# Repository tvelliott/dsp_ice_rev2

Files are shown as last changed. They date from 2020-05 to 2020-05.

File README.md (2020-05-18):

<html>
<b>480 MHz STM32H743 + ICE40 8K FGPA development board with 10/100 Ethernet interface 
<BR>
<BR><B>DSP_ICE_REV2
<BR>
<p>
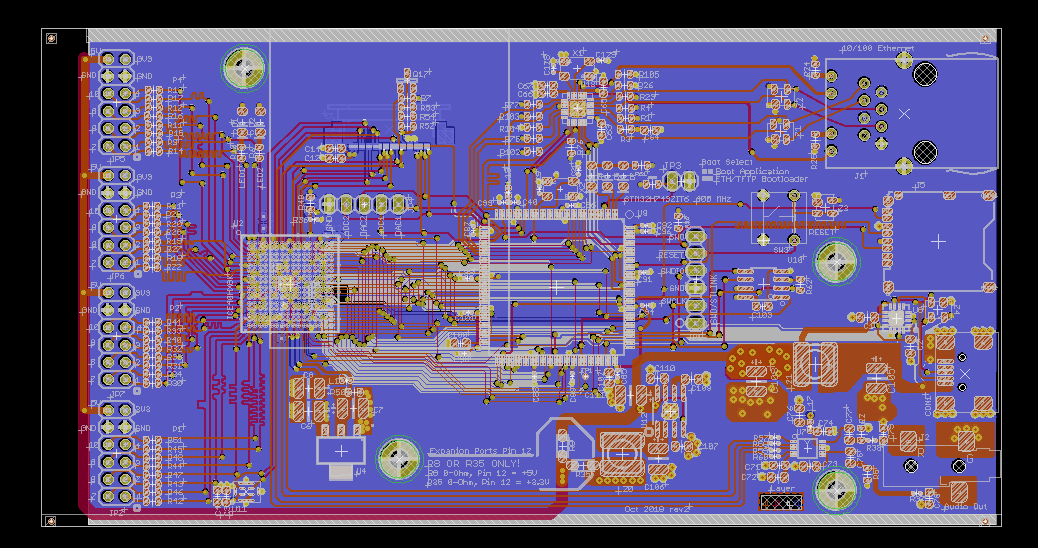
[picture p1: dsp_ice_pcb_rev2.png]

<BR>
<BR>
Features
<BR>
<BR>
<PRE>
16-bit FSMC Interface between MCU <> FPGA  (DMA is supported)
3.5mm audio jack with high quality I2S DAC.  I2S can be generated from FPGA or MCU
FPGA clock input / PLL is fed from MCU MC0 output
Low Noise 3.3V supply
4 PMOD-style ports with 3.3V or 5V selectable voltages
10/100 Mbps Ethernet Interface  (DMA supported,  90+ Mbps IPerf results)
PDM Microphone connected to FPGA
</PRE>
  
<BR><BR>If you are looking for something similar, but with firmware / HDL code already available,  take a look at DSP_ICE Rev 1 here
<BR>https://github.com/tvelliott/dsp_ice 
</html>

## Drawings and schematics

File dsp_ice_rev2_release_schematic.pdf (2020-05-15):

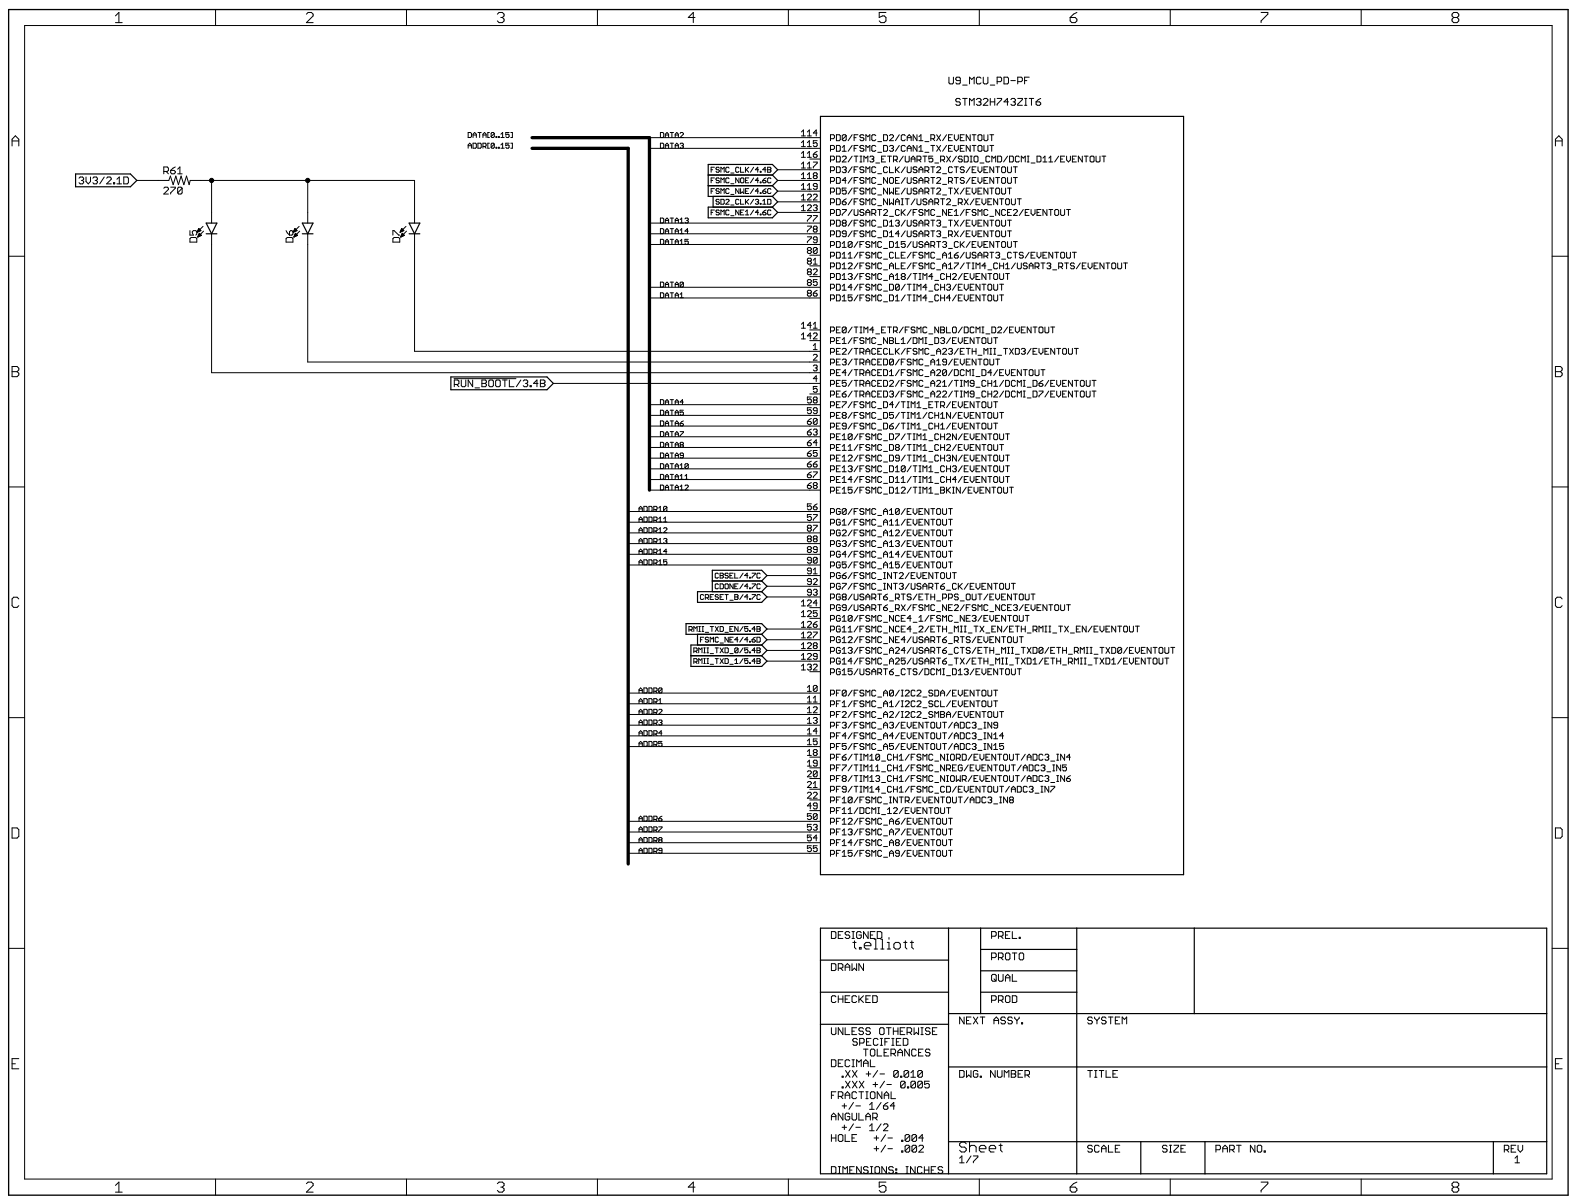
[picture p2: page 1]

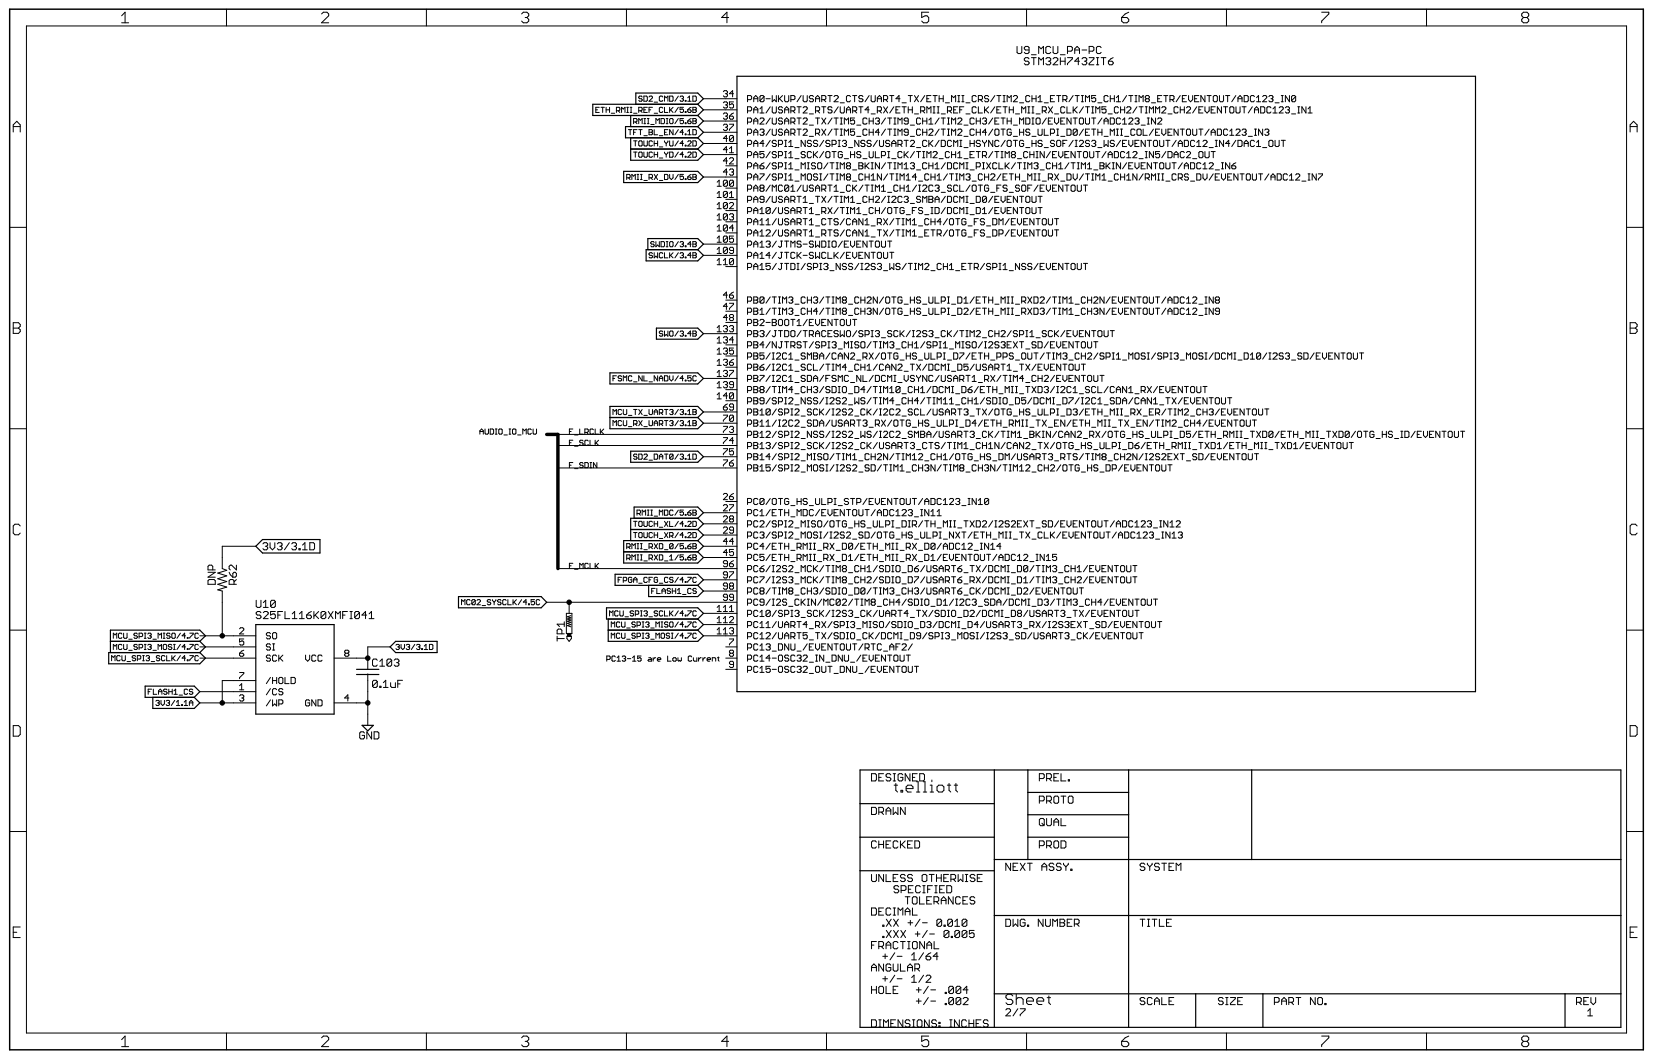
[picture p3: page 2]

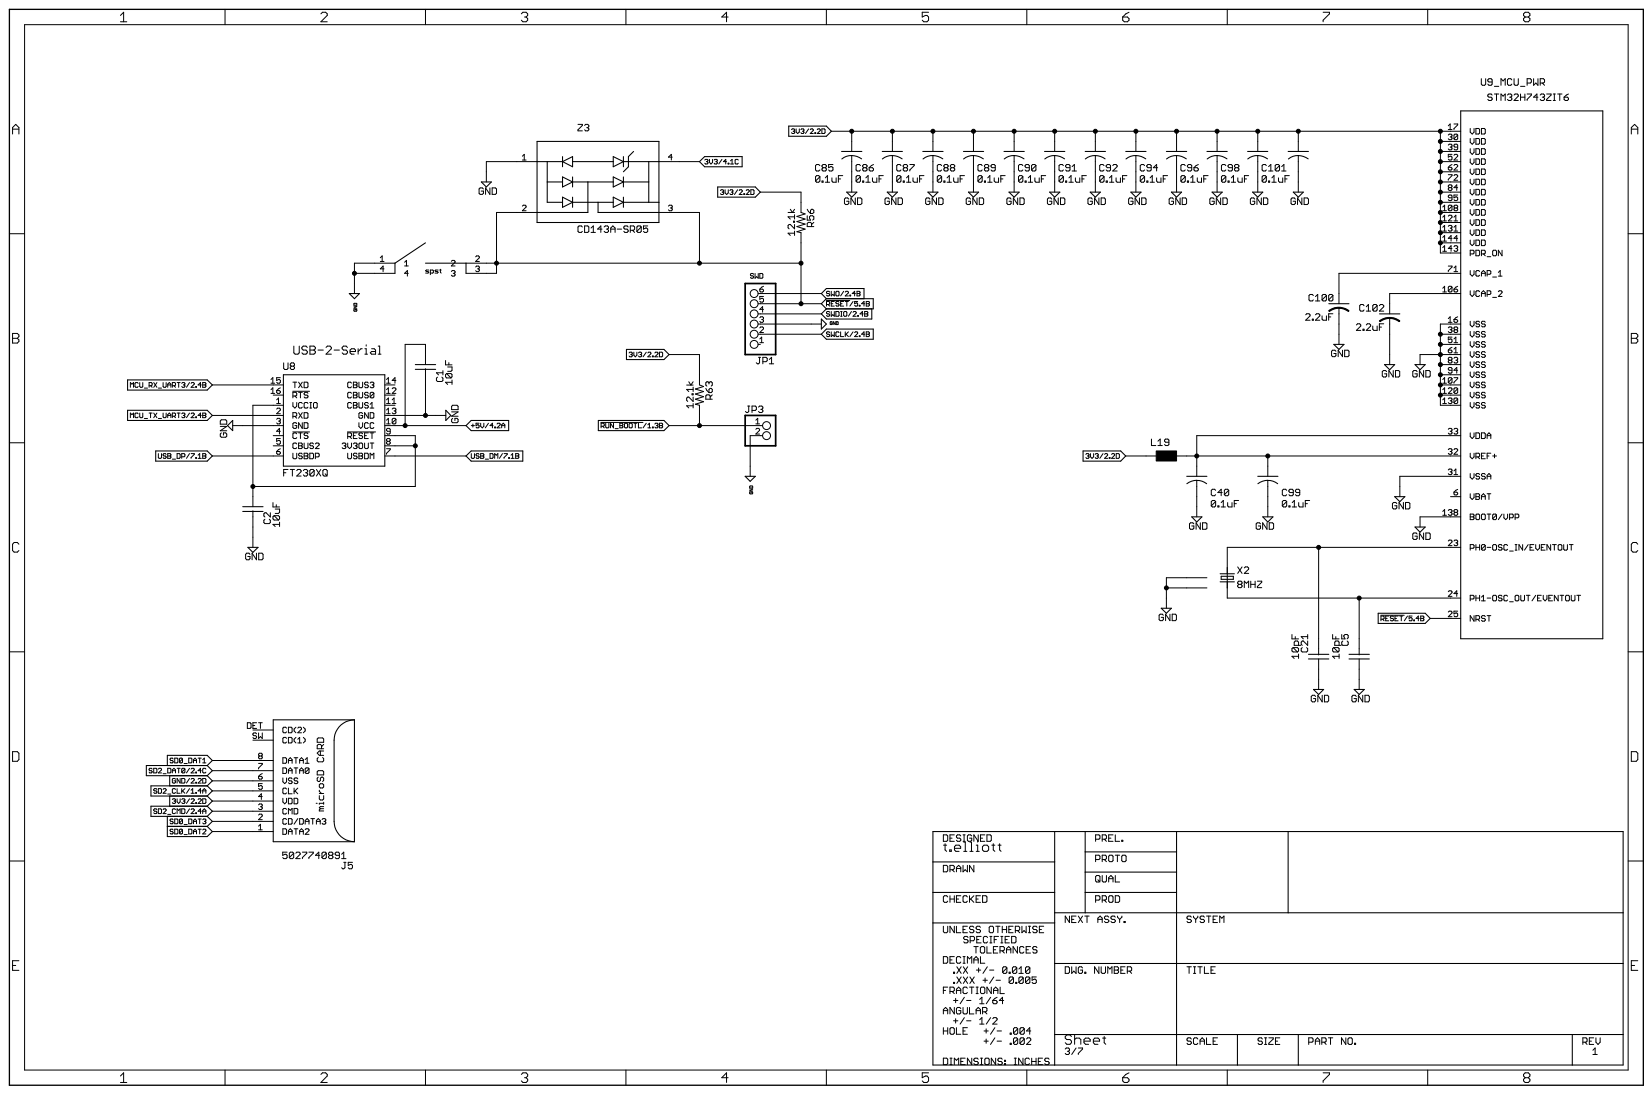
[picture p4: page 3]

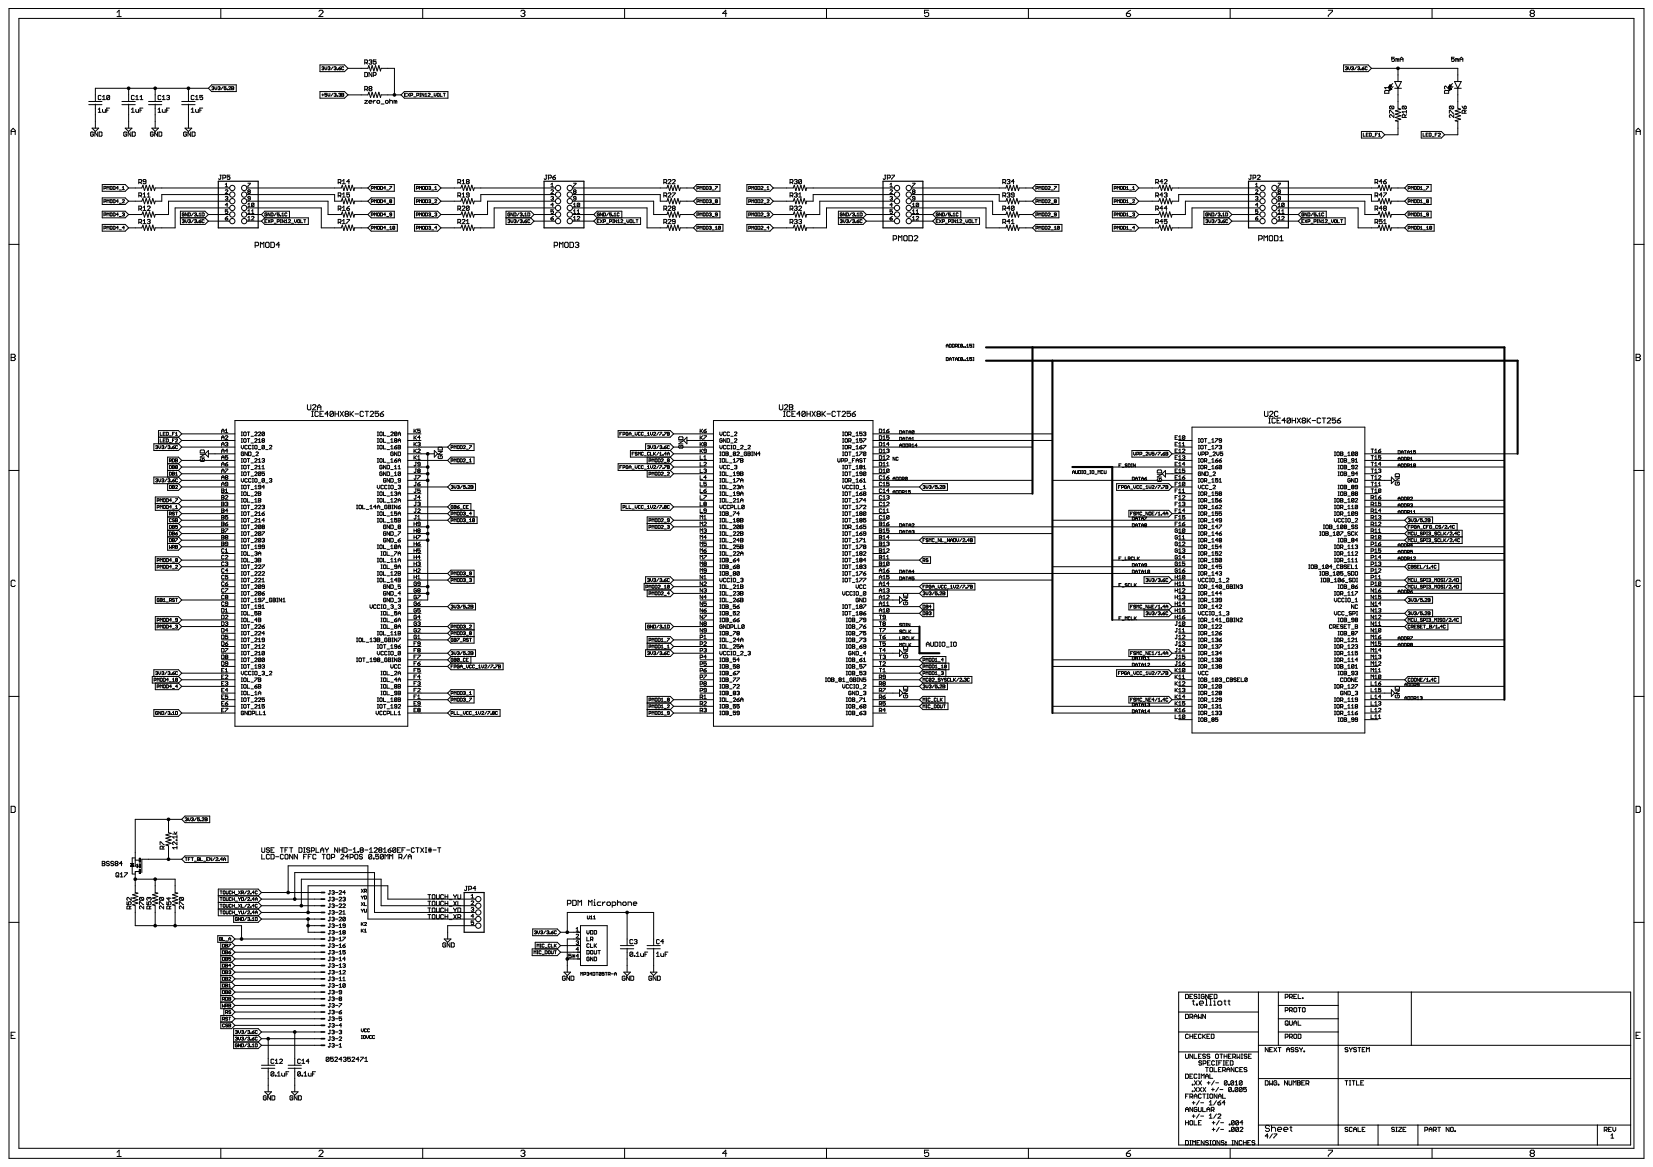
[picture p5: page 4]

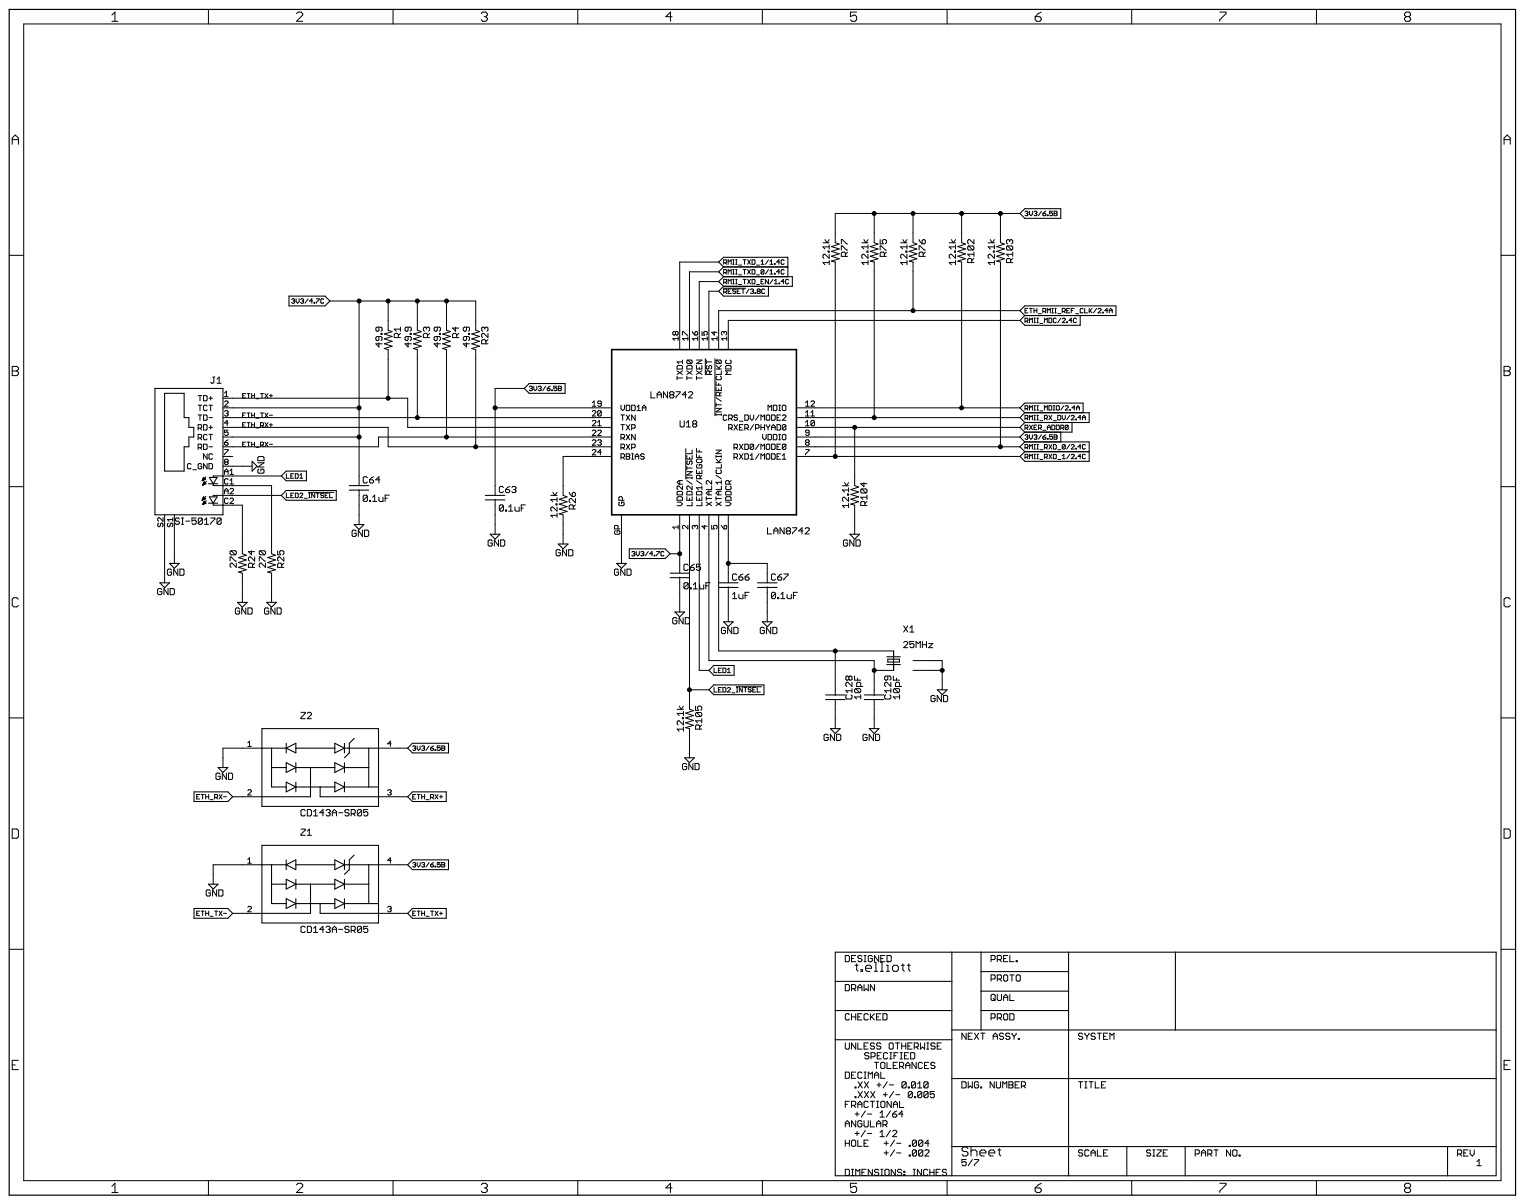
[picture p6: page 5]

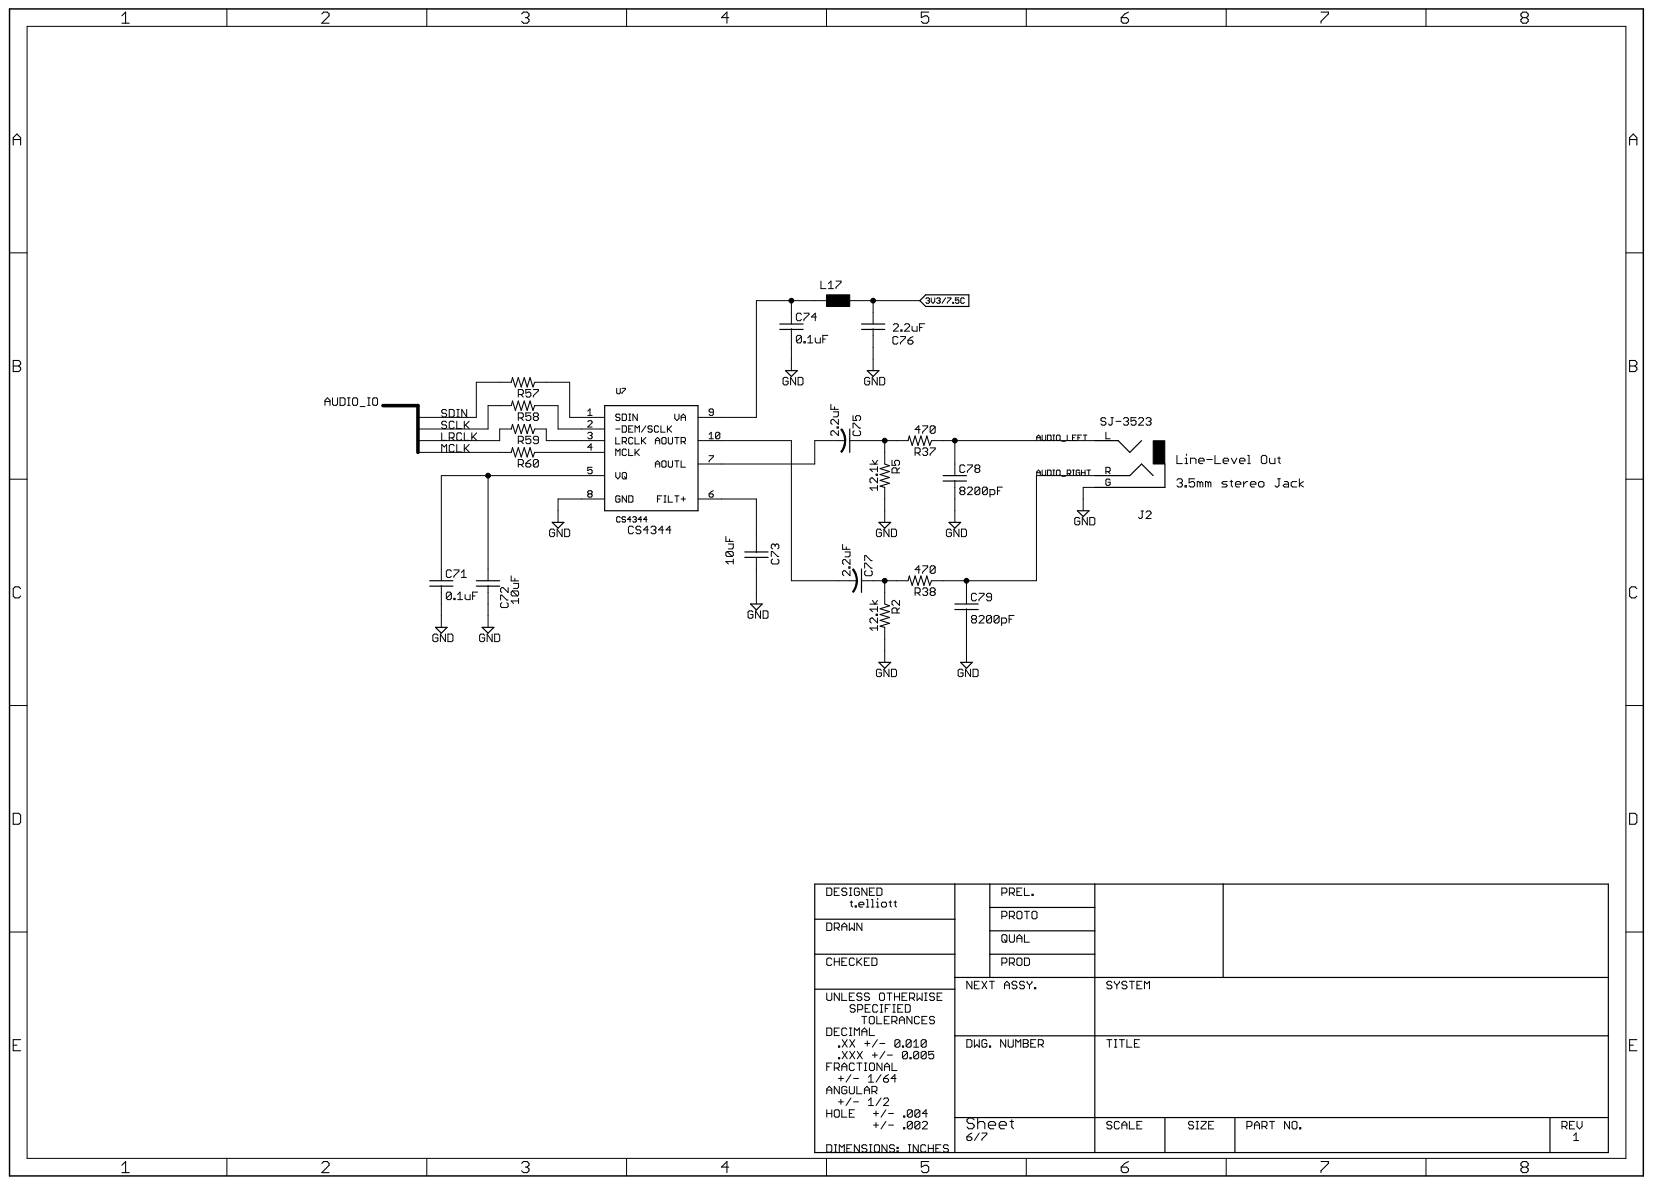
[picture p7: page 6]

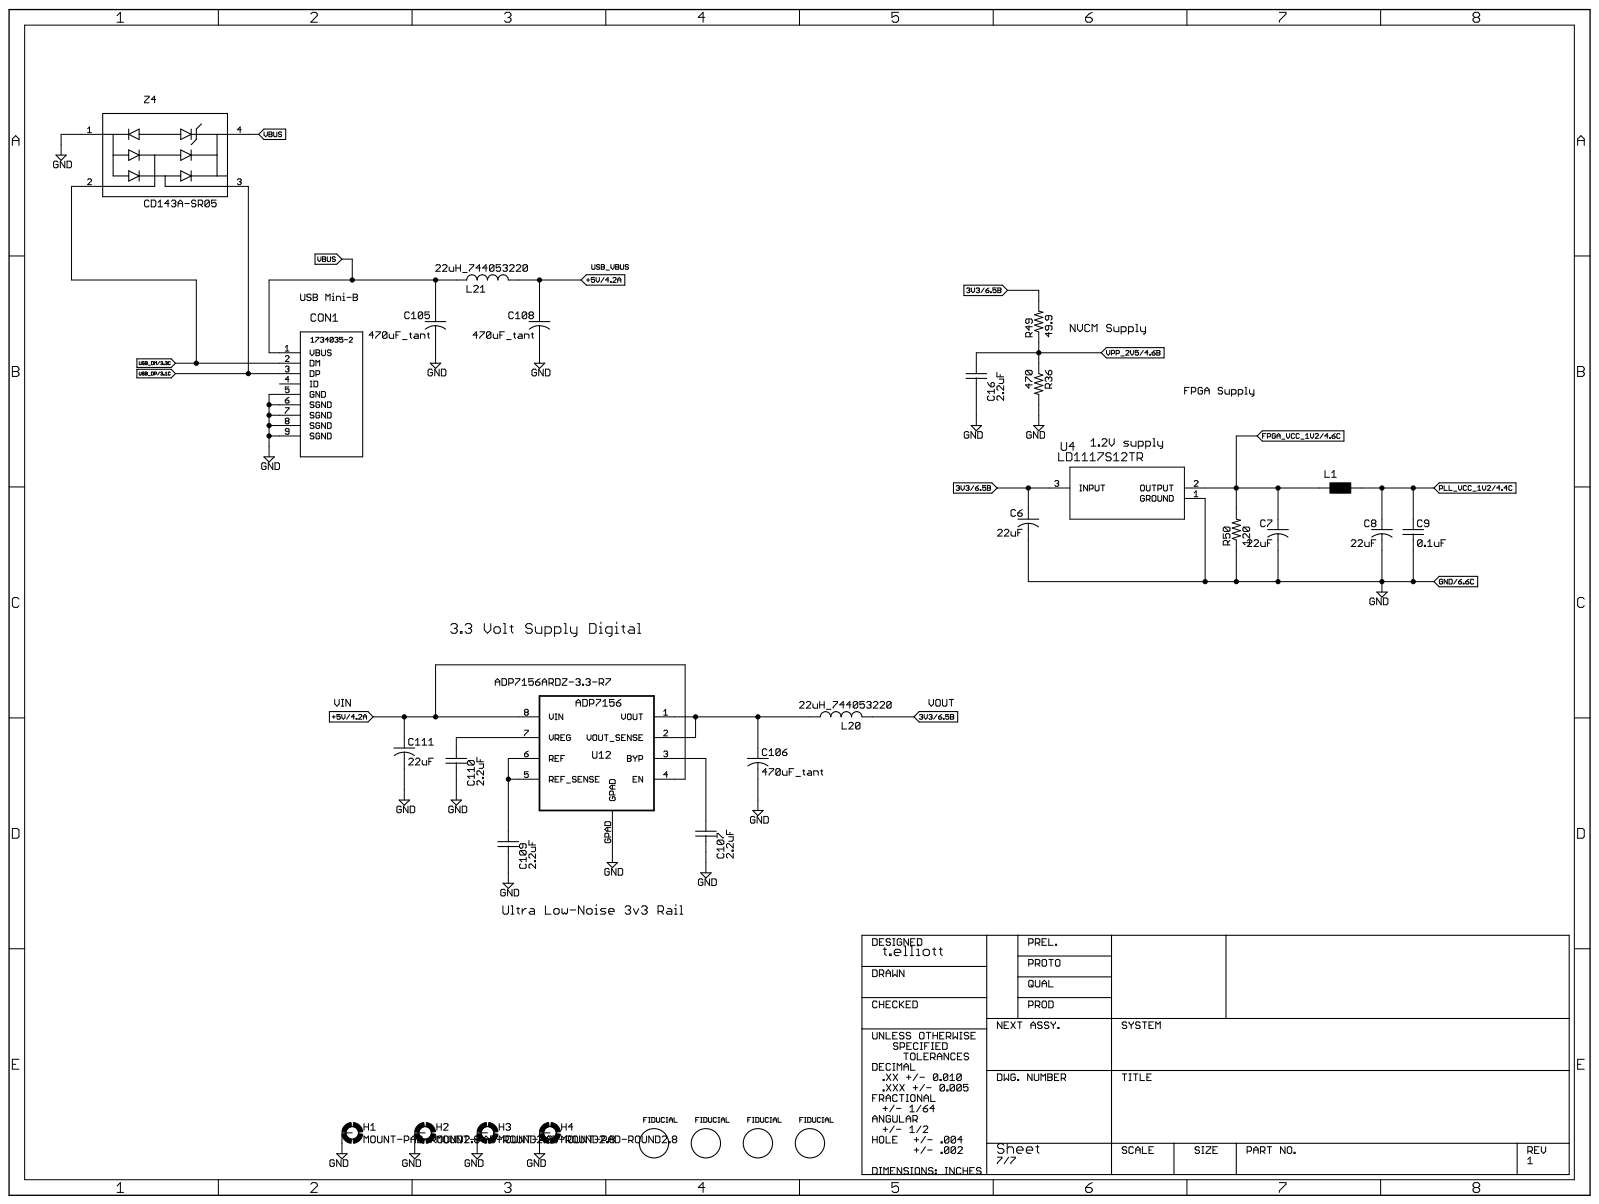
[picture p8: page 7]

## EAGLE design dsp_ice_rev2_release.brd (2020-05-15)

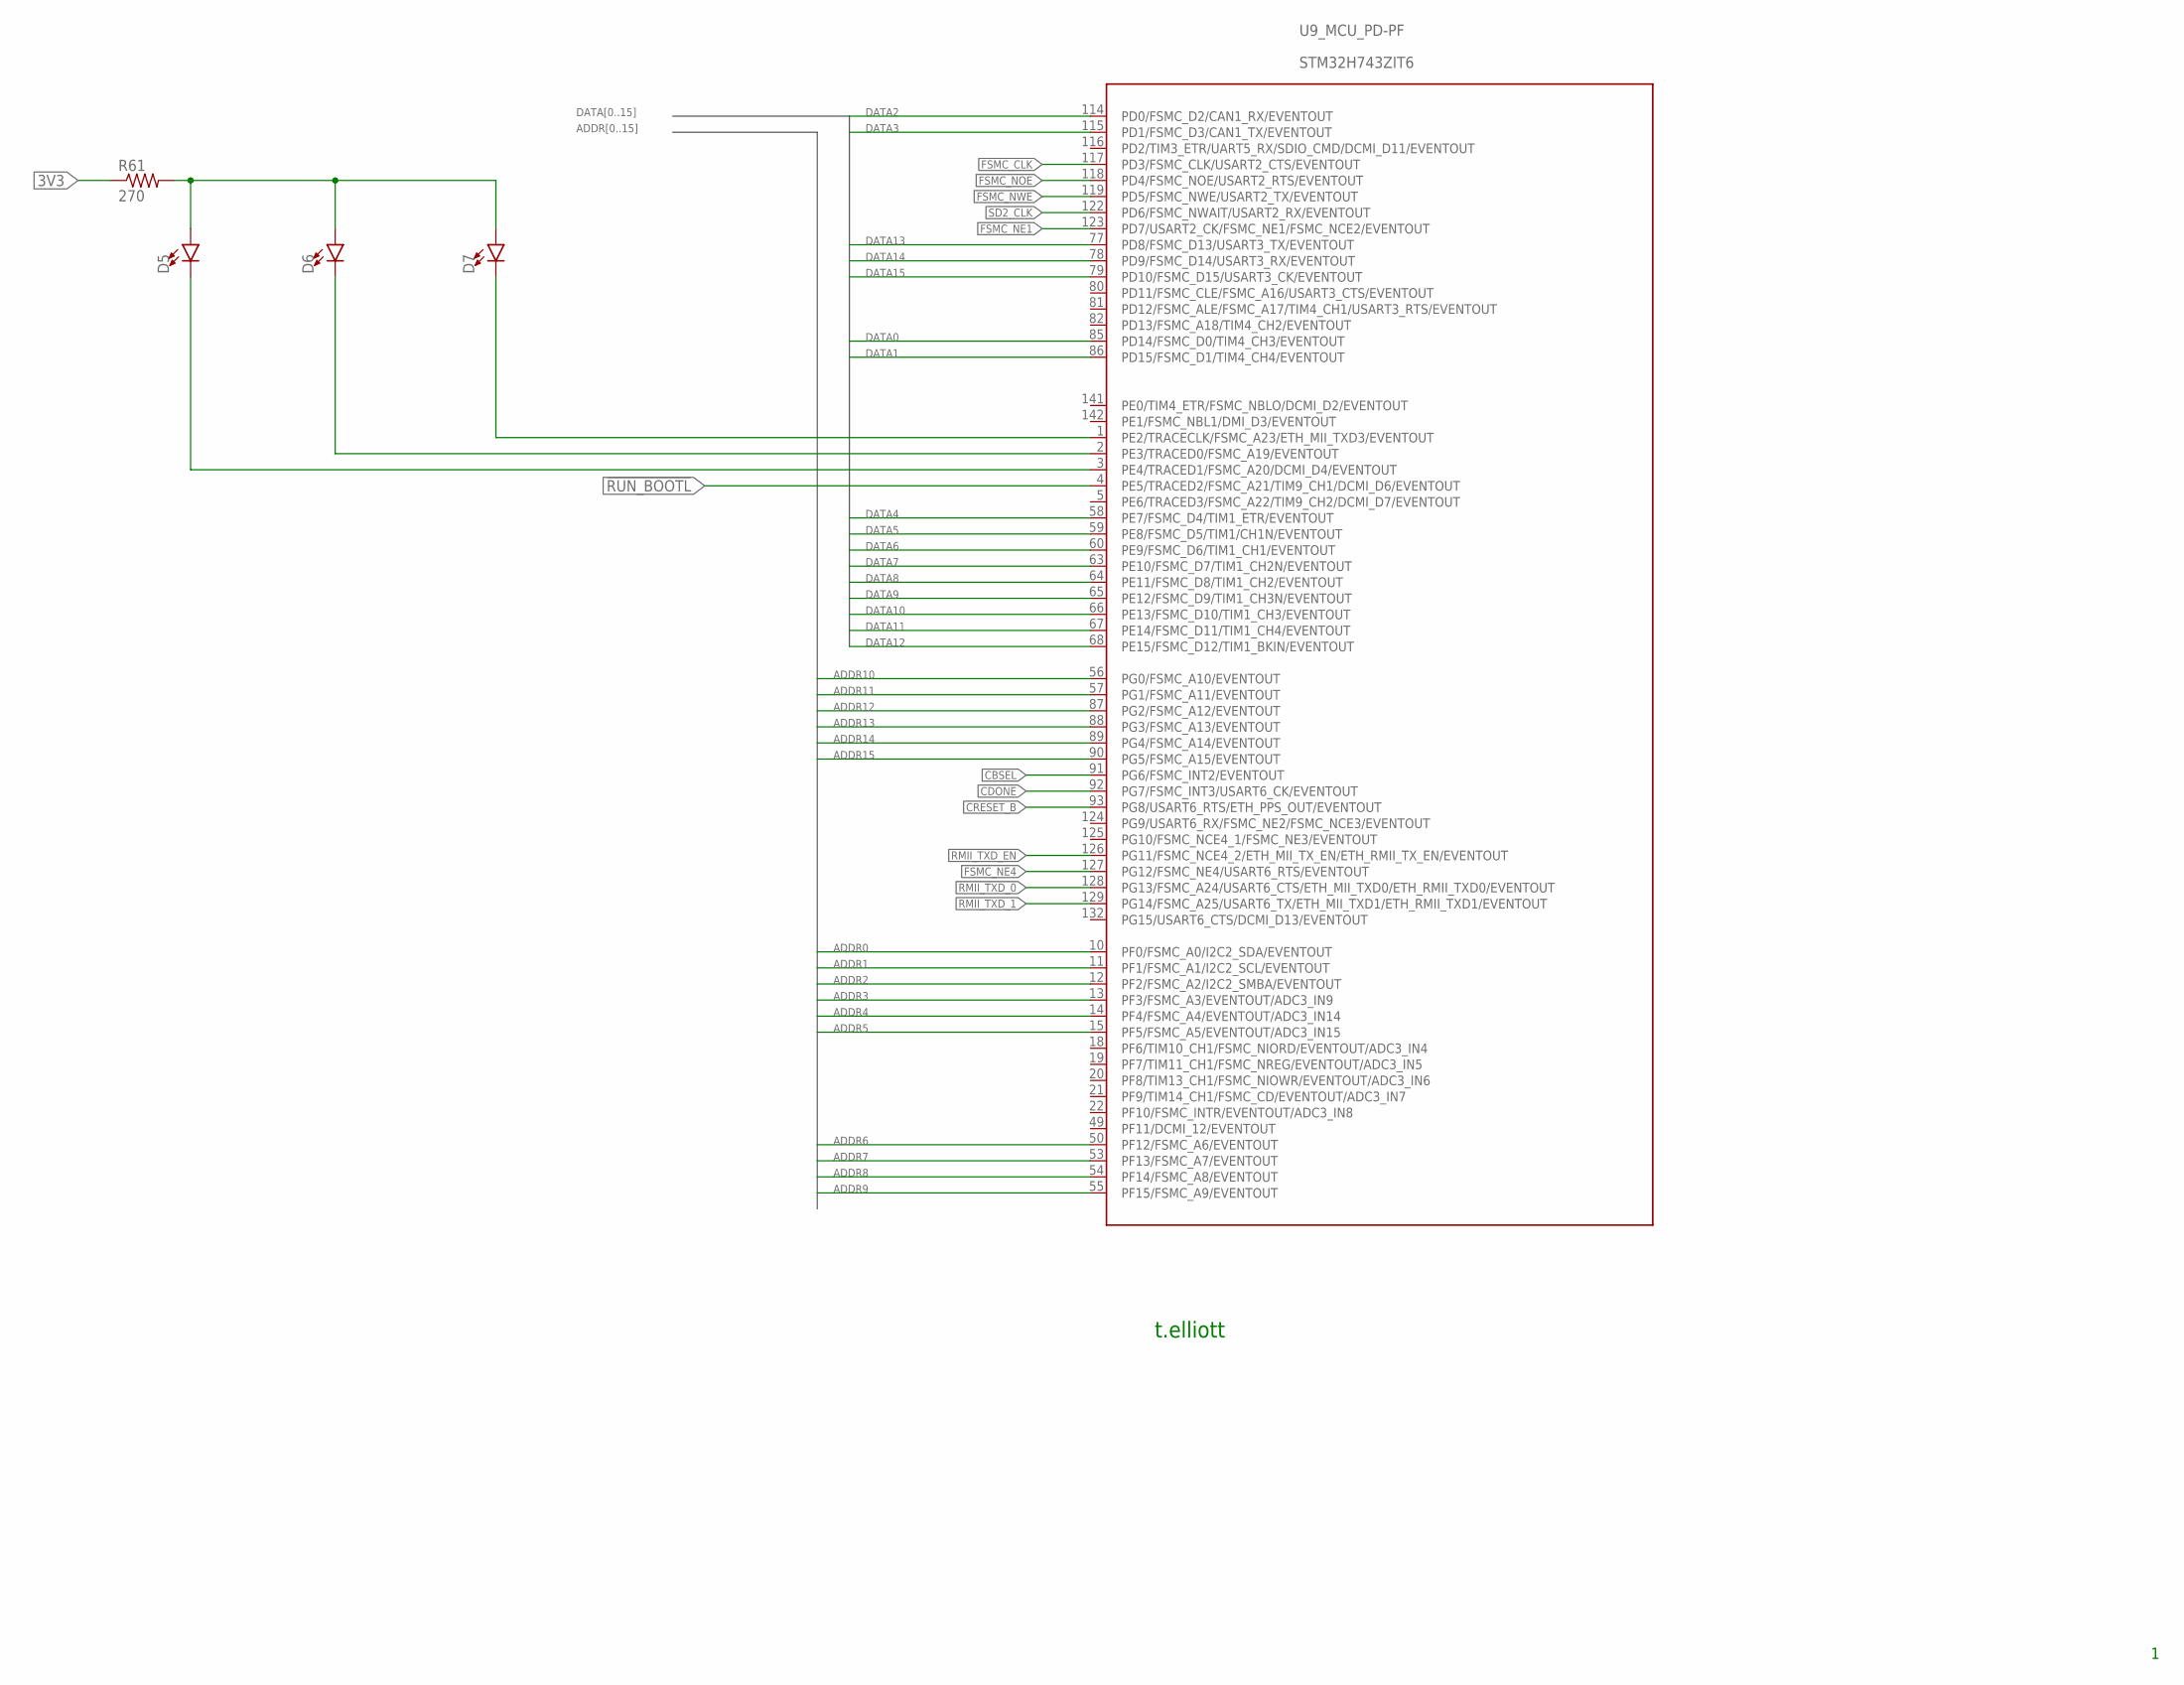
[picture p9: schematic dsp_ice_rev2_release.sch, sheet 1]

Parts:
D5, D6, D7: LED1206; LED-1206
R61: 270; R0603
U9: STM32H743ZIT6; STM32F407_144

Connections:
3V3: R61.1; also elsewhere on the board
!RUN_BOOTL: U9.4 (PE5/TRACED2/FSMC_A21/TIM9_CH1/DCMI_D6/E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); also elsewhere on the board
ADDR0: U9.10 (PF0/FSMC_A0/I2C2_SDA/EVENTOUT); also elsewhere on the board
ADDR1: U9.11 (PF1/FSMC_A1/I2C2_SCL/EVENTOUT); also elsewhere on the board
ADDR2: U9.12 (PF2/FSMC_A2/I2C2_SMBA/EVENTOUT); also elsewhere on the board
ADDR3: U9.13 (PF3/FSMC_A3/EVENTOUT/ADC3_IN9); also elsewhere on the board
ADDR4: U9.14 (PF4/FSMC_A4/EVENTOUT/ADC3_IN14); also elsewhere on the board
ADDR5: U9.15 (PF5/FSMC_A5/EVENTOUT/ADC3_IN15); also elsewhere on the board
ADDR6: U9.50 (PF12/FSMC_A6/EVENTOUT); also elsewhere on the board
ADDR7: U9.53 (PF13/FSMC_A7/EVENTOUT); also elsewhere on the board
ADDR8: U9.54 (PF14/FSMC_A8/EVENTOUT); also elsewhere on the board
ADDR9: U9.55 (PF15/FSMC_A9/EVENTOUT); also elsewhere on the board
ADDR10: U9.56 (PG0/FSMC_A10/EVENTOUT); also elsewhere on the board
ADDR11: U9.57 (PG1/FSMC_A11/EVENTOUT); also elsewhere on the board
ADDR12: U9.87 (PG2/FSMC_A12/EVENTOUT); also elsewhere on the board
ADDR13: U9.88 (PG3/FSMC_A13/EVENTOUT); also elsewhere on the board
ADDR14: U9.89 (PG4/FSMC_A14/EVENTOUT); also elsewhere on the board
ADDR15: U9.90 (PG5/FSMC_A15/EVENTOUT); also elsewhere on the board
CBSEL: U9.91 (PG6/FSMC_INT2/EVENTOUT); also elsewhere on the board
CDONE: U9.92 (PG7/FSMC_INT3/USART6_CK/EVENTOUT); also elsewhere on the board
CRESET_B: U9.93 (PG8/USART6_RTS/ETH_PPS_OUT/EVENTOUT); also elsewhere on the board
DATA0: U9.85 (PD14/FSMC_D0/TIM4_CH3/EVENTOUT); also elsewhere on the board
DATA1: U9.86 (PD15/FSMC_D1/TIM4_CH4/EVENTOUT); also elsewhere on the board
DATA2: U9.114 (PD0/FSMC_D2/CAN1_RX/EVENTOUT); also elsewhere on the board
DATA3: U9.115 (PD1/FSMC_D3/CAN1_TX/EVENTOUT); also elsewhere on the board
DATA4: U9.58 (PE7/FSMC_D4/TIM1_ETR/EVENTOUT); also elsewhere on the board
DATA5: U9.59 (PE8/FSMC_D5/TIM1/CH1N/EVENTOUT); also elsewhere on the board
DATA6: U9.60 (PE9/FSMC_D6/TIM1_CH1/EVENTOUT); also elsewhere on the board
DATA7: U9.63 (PE10/FSMC_D7/TIM1_CH2N/EVENTOUT); also elsewhere on the board
DATA8: U9.64 (PE11/FSMC_D8/TIM1_CH2/EVENTOUT); also elsewhere on the board
DATA9: U9.65 (PE12/FSMC_D9/TIM1_CH3N/EVENTOUT); also elsewhere on the board
DATA10: U9.66 (PE13/FSMC_D10/TIM1_CH3/EVENTOUT); also elsewhere on the board
DATA11: U9.67 (PE14/FSMC_D11/TIM1_CH4/EVENTOUT); also elsewhere on the board
DATA12: U9.68 (PE15/FSMC_D12/TIM1_BKIN/EVENTOUT); also elsewhere on the board
DATA13: U9.77 (PD8/FSMC_D13/USART3_TX/EVENTOUT); also elsewhere on the board
DATA14: U9.78 (PD9/FSMC_D14/USART3_RX/EVENTOUT); also elsewhere on the board
DATA15: U9.79 (PD10/FSMC_D15/USART3_CK/EVENTOUT); also elsewhere on the board
FSMC_CLK: U9.117 (PD3/FSMC_CLK/USART2_CTS/EVENTOUT); also elsewhere on the board
FSMC_NE1: U9.123 (PD7/USART2_CK/FSMC_NE1/FSMC_NCE2/EVENTO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); also elsewhere on the board
FSMC_NE4: U9.127 (PG12/FSMC_NE4/USART6_RTS/EVENTOUT); also elsewhere on the board
FSMC_NOE: U9.118 (PD4/FSMC_NOE/USART2_RTS/EVENTOUT); also elsewhere on the board
FSMC_NWE: U9.119 (PD5/FSMC_NWE/USART2_TX/EVENTOUT); also elsewhere on the board
unnamed: D5.A, D6.A, D7.A, R61.2
unnamed: D7.C, U9.1 (PE2/TRACECLK/FSMC_A23/ETH_MII_TXD3/EVEN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)
unnamed: D6.C, U9.2 (PE3/TRACED0/FSMC_A19/EVENTOUT)
unnamed: D5.C, U9.3 (PE4/TRACED1/FSMC_A20/DCMI_D4/EVENTOUT)
RMII_TXD_0: U9.128 (PG13/FSMC_A24/USART6_CTS/ETH_MII_TXD0/E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); also elsewhere on the board
RMII_TXD_1: U9.129 (PG14/FSMC_A25/USART6_TX/ETH_MII_TXD1/ET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); also elsewhere on the board
RMII_TXD_EN: U9.126 (PG11/FSMC_NCE4_2/ETH_MII_TX_EN/ETH_RMII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); also elsewhere on the board
SD2_CLK: U9.122 (PD6/FSMC_NWAIT/USART2_RX/EVENTOUT); also elsewhere on the board

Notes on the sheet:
t.elliott

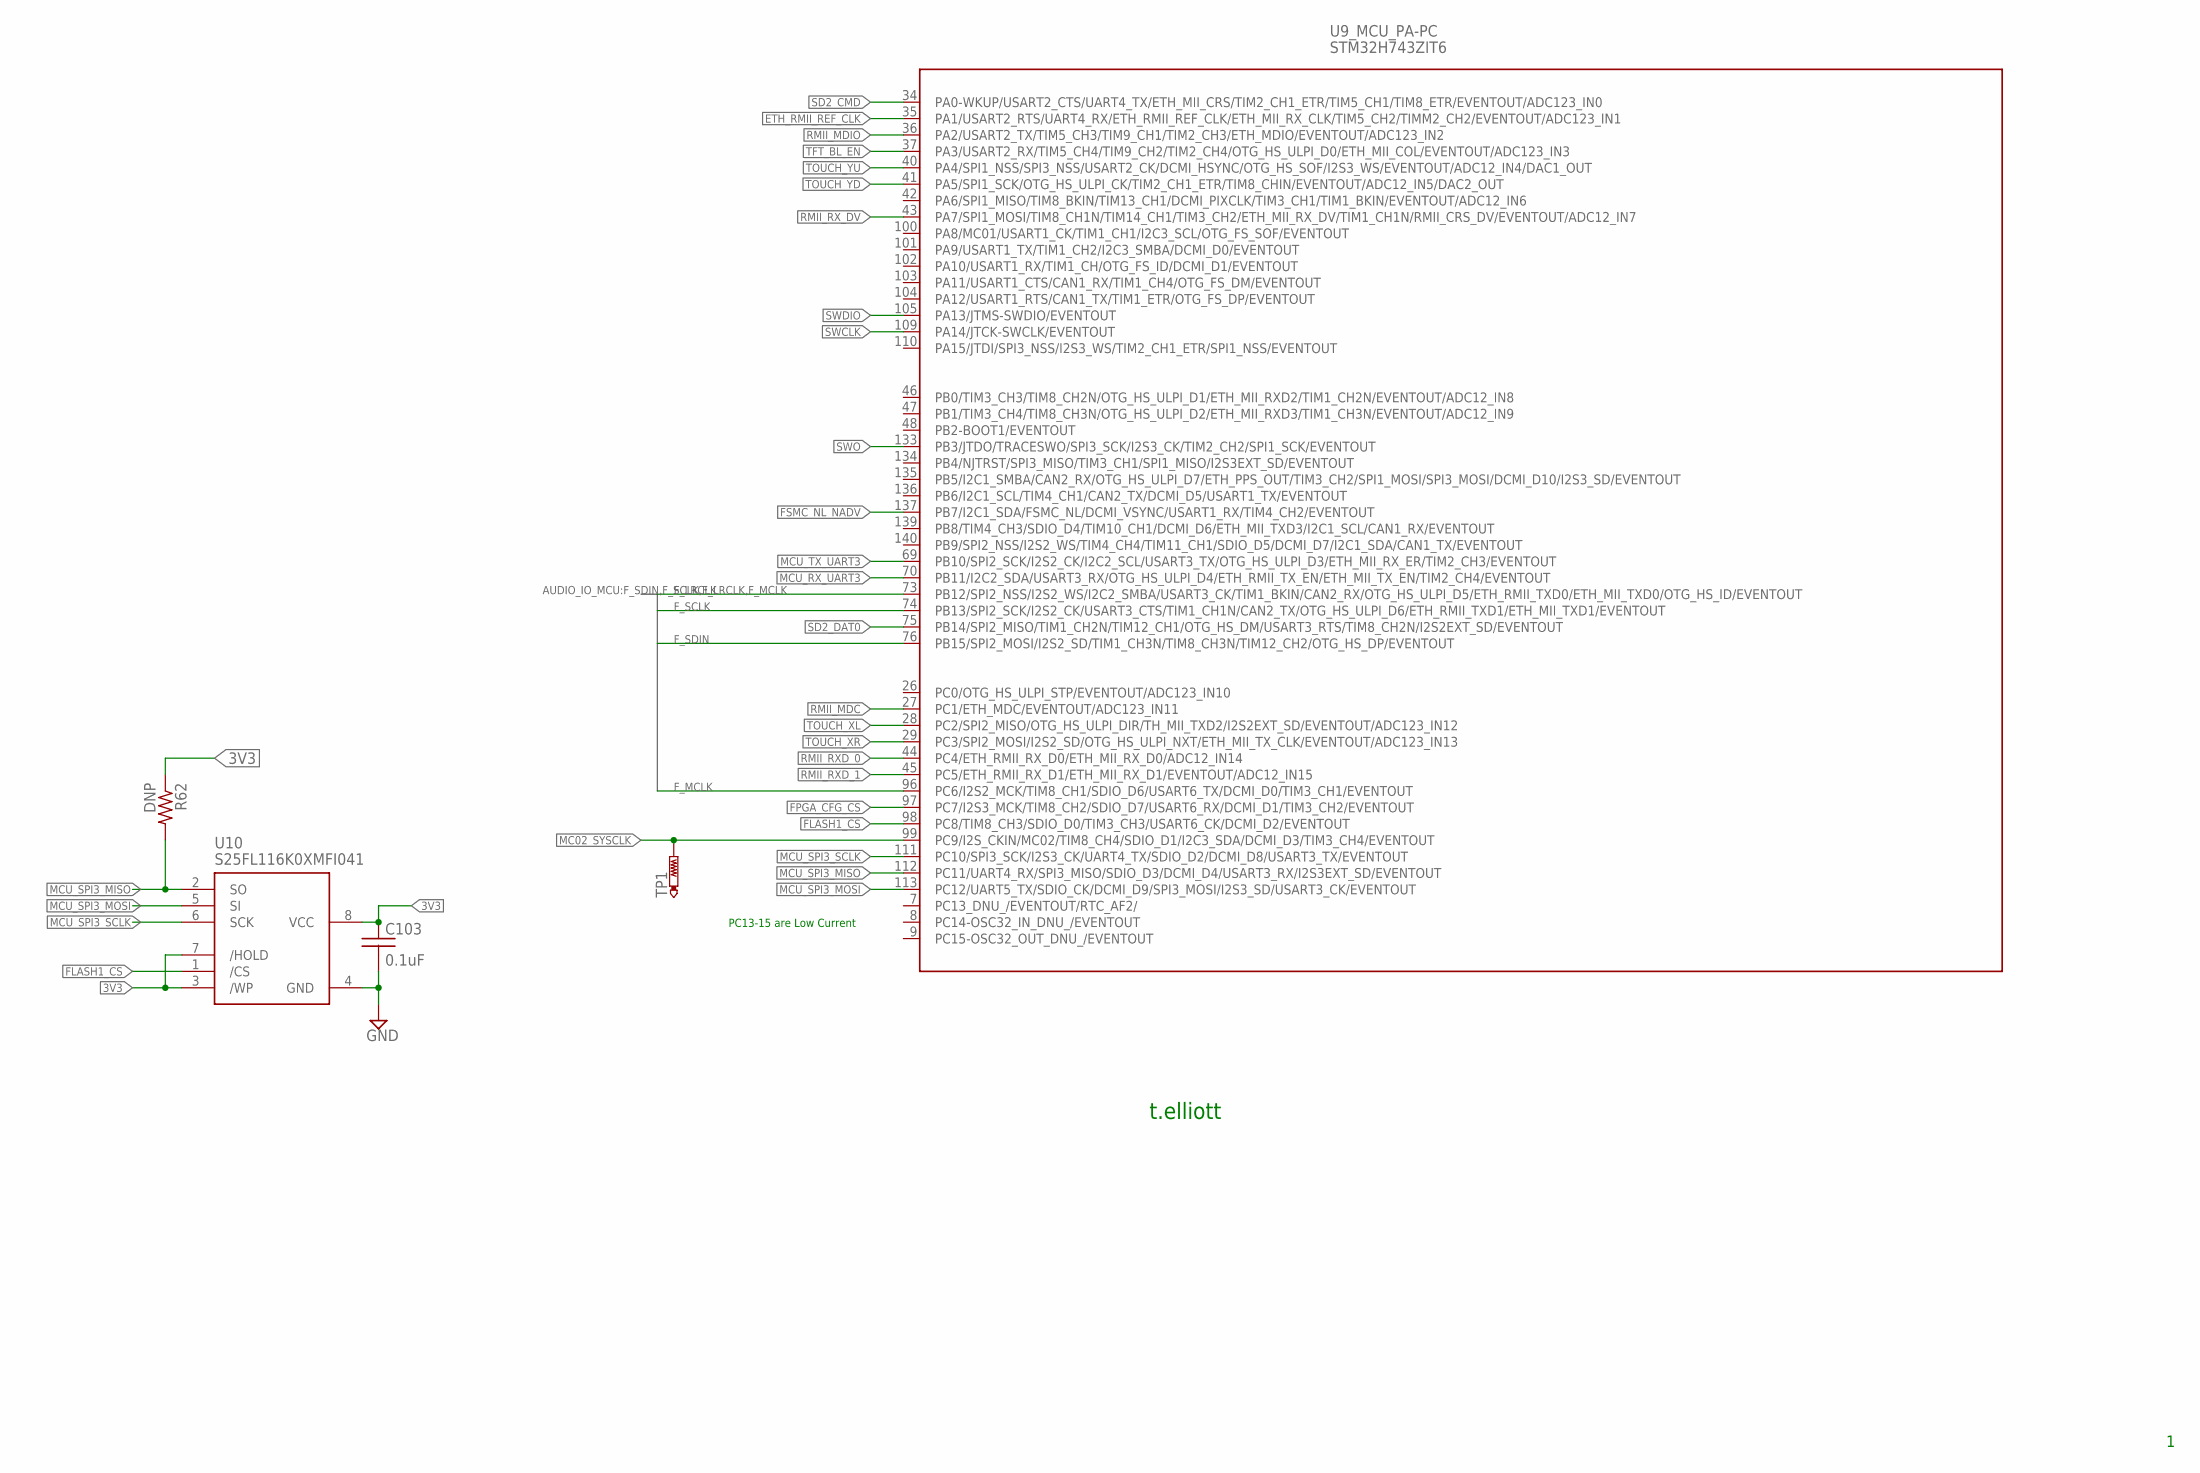
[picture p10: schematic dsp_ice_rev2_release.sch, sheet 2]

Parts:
C103: 0.1uF; C0603
R62: DNP; R0603
TP1: PTR1TP08R; TP08R
U9: STM32H743ZIT6; STM32F407_144
U10: S25FL116K0XMFI041; SO8

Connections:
3V3: C103.1, R62.1, U10.3 (/WP), U10.7 (/HOLD), U10.8 (VCC); also elsewhere on the board
ETH_RMII_REF_CLK: U9.35 (PA1/USART2_RTS/UART4_RX/ETH_RMII_REF_CL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); also elsewhere on the board
FLASH1_CS: U9.98 (PC8/TIM8_CH3/SDIO_D0/TIM3_CH3/USART6_CK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), U10.1 (/CS)
FPGA_CFG_CS: U9.97 (PC7/I2S3_MCK/TIM8_CH2/SDIO_D7/USART6_RX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); also elsewhere on the board
FSMC_NL_NADV: U9.137 (PB7/I2C1_SDA/FSMC_NL/DCMI_VSYNC/USART1_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); also elsewhere on the board
F_LRCLK: U9.73 (PB12/SPI2_NSS/I2S2_WS/I2C2_SMBA/USART3_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); also elsewhere on the board
F_MCLK: U9.96 (PC6/I2S2_MCK/TIM8_CH1/SDIO_D6/USART6_TX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); also elsewhere on the board
F_SCLK: U9.74 (PB13/SPI2_SCK/I2S2_CK/USART3_CTS/TIM1_C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); also elsewhere on the board
F_SDIN: U9.76 (PB15/SPI2_MOSI/I2S2_SD/TIM1_CH3N/TIM8_C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); also elsewhere on the board
GND: C103.2, U10.4 (GND); also elsewhere on the board
MC02_SYSCLK: TP1.TP, U9.99 (PC9/I2S_CKIN/MC02/TIM8_CH4/SDIO_D1/I2C3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); also elsewhere on the board
MCU_RX_UART3: U9.70 (PB11/I2C2_SDA/USART3_RX/OTG_HS_ULPI_D4/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); also elsewhere on the board
MCU_SPI3_MISO: R62.2, U9.112 (PC11/UART4_RX/SPI3_MISO/SDIO_D3/DCMI_D4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), U10.2 (SO); also elsewhere on the board
MCU_SPI3_MOSI: U9.113 (PC12/UART5_TX/SDIO_CK/DCMI_D9/SPI3_MOSI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), U10.5 (SI); also elsewhere on the board
MCU_SPI3_SCLK: U9.111 (PC10/SPI3_SCK/I2S3_CK/UART4_TX/SDIO_D2/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), U10.6 (SCK); also elsewhere on the board
MCU_TX_UART3: U9.69 (PB10/SPI2_SCK/I2S2_CK/I2C2_SCL/USART3_T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); also elsewhere on the board
RMII_MDC: U9.27 (PC1/ETH_MDC/EVENTOUT/ADC123_IN11); also elsewhere on the board
RMII_MDIO: U9.36 (PA2/USART2_TX/TIM5_CH3/TIM9_CH1/TIM2_CH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); also elsewhere on the board
RMII_RXD_0: U9.44 (PC4/ETH_RMII_RX_D0/ETH_MII_RX_D0/ADC12_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); also elsewhere on the board
RMII_RXD_1: U9.45 (PC5/ETH_RMII_RX_D1/ETH_MII_RX_D1/EVENTO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); also elsewhere on the board
RMII_RX_DV: U9.43 (PA7/SPI1_MOSI/TIM8_CH1N/TIM14_CH1/TIM3_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); also elsewhere on the board
SD2_CMD: U9.34 (PA0-WKUP/USART2_CTS/UART4_TX/ETH_MII_CR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); also elsewhere on the board
SD2_DAT0: U9.75 (PB14/SPI2_MISO/TIM1_CH2N/TIM12_CH1/OTG_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); also elsewhere on the board
SWCLK: U9.109 (PA14/JTCK-SWCLK/EVENTOUT); also elsewhere on the board
SWDIO: U9.105 (PA13/JTMS-SWDIO/EVENTOUT); also elsewhere on the board
SWO: U9.133 (PB3/JTDO/TRACESWO/SPI3_SCK/I2S3_CK/TIM2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); also elsewhere on the board
TFT_BL_EN: U9.37 (PA3/USART2_RX/TIM5_CH4/TIM9_CH2/TIM2_CH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); also elsewhere on the board
TOUCH_XL: U9.28 (PC2/SPI2_MISO/OTG_HS_ULPI_DIR/TH_MII_TX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); also elsewhere on the board
TOUCH_XR: U9.29 (PC3/SPI2_MOSI/I2S2_SD/OTG_HS_ULPI_NXT/E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); also elsewhere on the board
TOUCH_YD: U9.41 (PA5/SPI1_SCK/OTG_HS_ULPI_CK/TIM2_CH1_ET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); also elsewhere on the board
TOUCH_YU: U9.40 (PA4/SPI1_NSS/SPI3_NSS/USART2_CK/DCMI_HS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); also elsewhere on the board

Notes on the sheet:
PC13-15 are Low Current
t.elliott

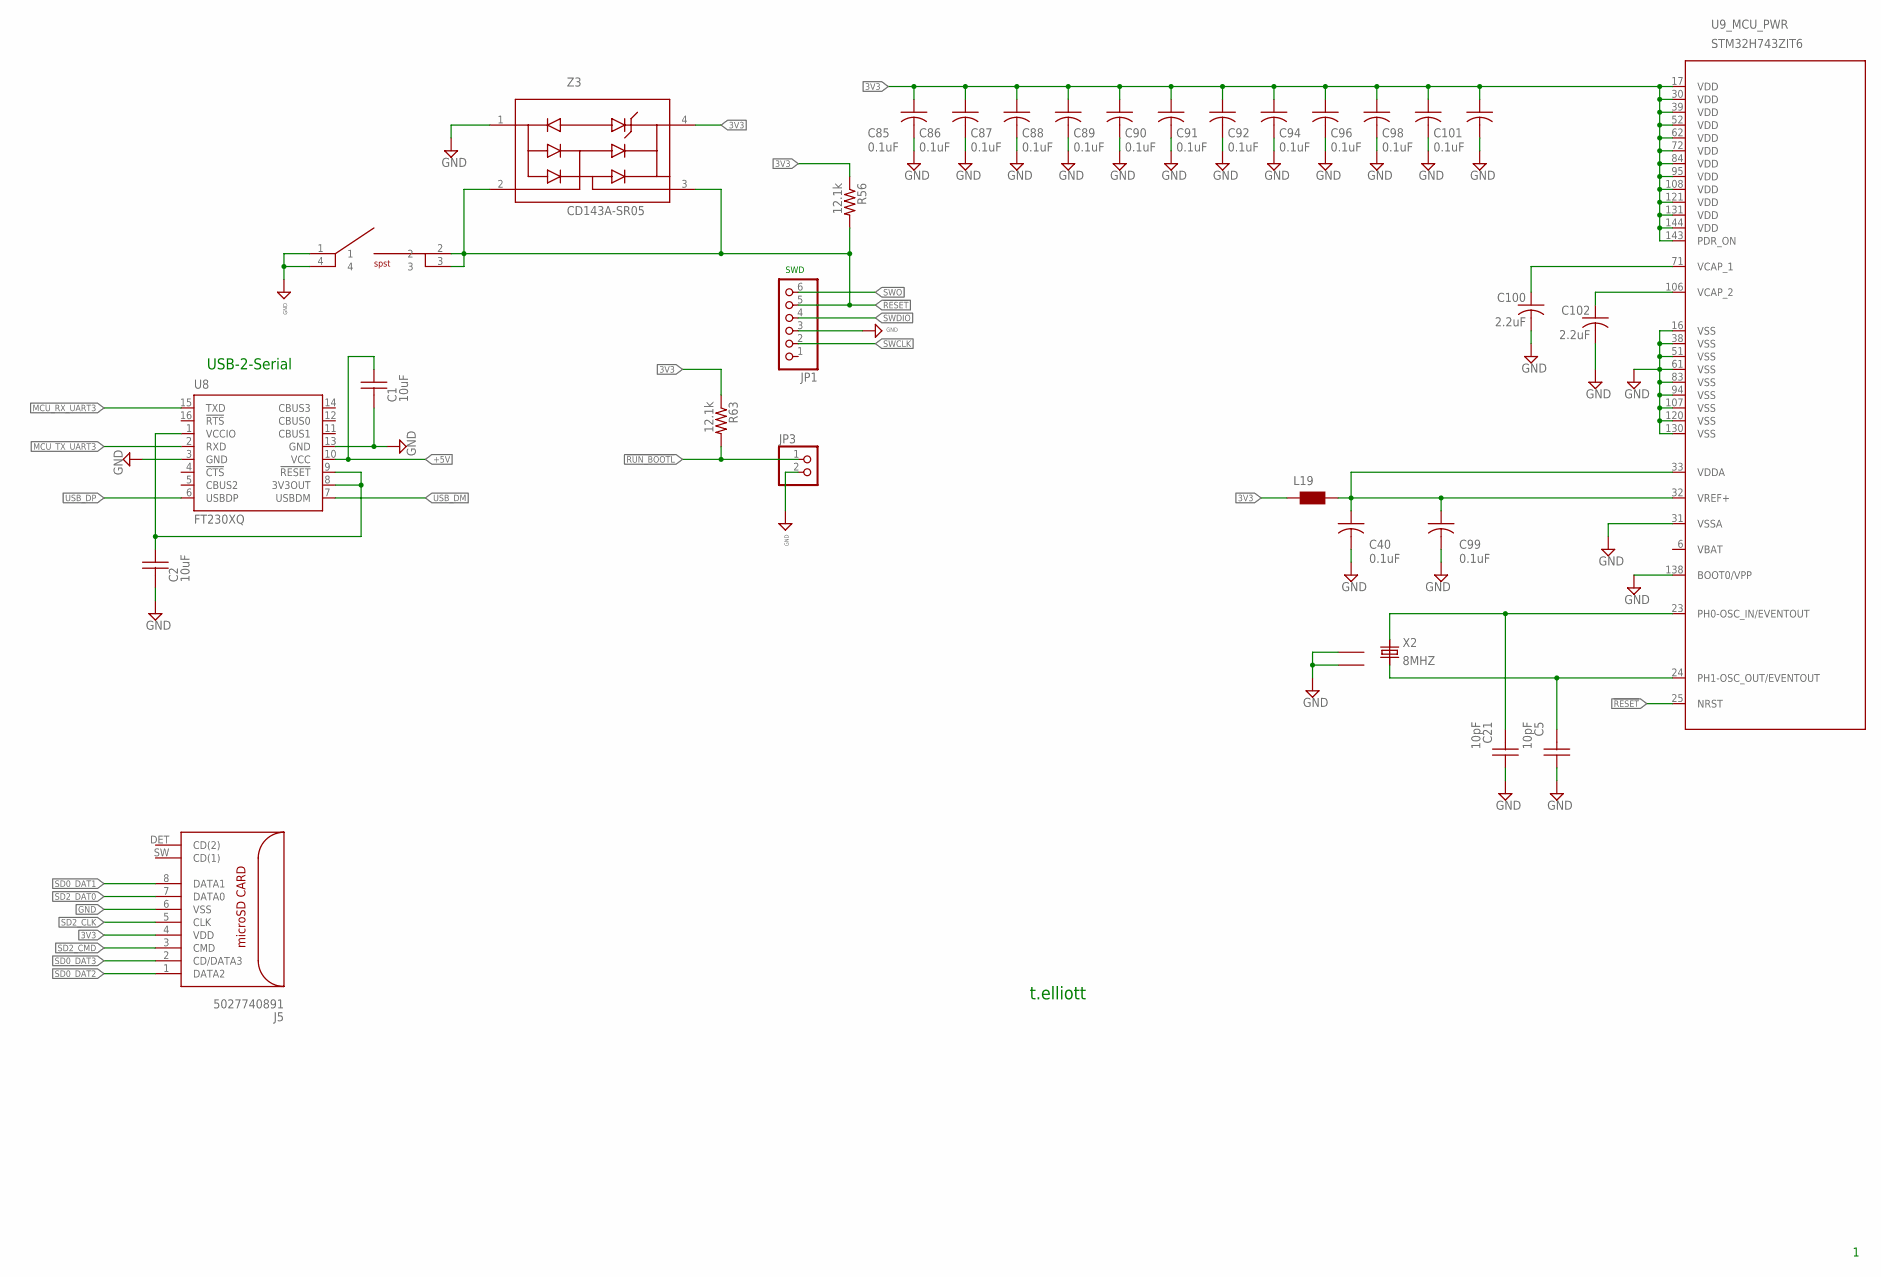
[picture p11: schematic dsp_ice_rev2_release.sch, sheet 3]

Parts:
C1, C2: 10uF; C0805
C5, C21: 10pF; C0402
C40, C85, C86, C87, C88, C89, C90, C91, C92, C94, C96, C98, C99, C101: 0.1uF; 0402
C100, C102: 2.2uF; C0805
J5: 5027740891; SD-502774-001
JP1: PINHD-1X6; 1X06
JP3: PINHD-1X2; 1X02
L19: WE-CBF_0603; 0603
R56, R63: 12.1k; R0603
SW3: HOKURIKU_KSM06_6X6MM_SWITCH1; TACTILE_6X6MM
U8: FT230XQ; QFN16
U9: STM32H743ZIT6; STM32F407_144
X2: 8MHZ; ECS-250-20-30B-DU_CRYSTAL
Z3: CD143A-SR05; SR2.8.TCT_1PRIMARY

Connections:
3V3: C85.1 (A), C86.1 (A), C87.1 (A), C88.1 (A), C89.1 (A), C90.1 (A), C91.1 (A), C92.1 (A), C94.1 (A), C96.1 (A), C98.1 (A), C101.1 (A), J5.4 (VDD), L19.1, R56.1, R63.1, U9.17 (VDD), U9.30 (VDD), U9.39 (VDD), U9.52 (VDD), U9.62 (VDD), U9.72 (VDD), U9.84 (VDD), U9.95 (VDD), U9.108 (VDD), U9.121 (VDD), U9.131 (VDD), U9.143 (PDR_ON), U9.144 (VDD), Z3.4 (REF); also elsewhere on the board
3V_ANALOG: C40.1 (A), C99.1 (A), L19.2, U9.32 (VREF+), U9.33 (VDDA)
20MHZ_REF: C21.2, U9.23 (PH0-OSC_IN/EVENTOUT), X2.1
!RESET: JP1.5, R56.2, SW3.2, SW3.3, U9.25 (NRST), Z3.2 (I/O), Z3.3 (I/O); also elsewhere on the board
!RUN_BOOTL: JP3.1, R63.2; also elsewhere on the board
+5V: C1.1, U8.10 (VCC); also elsewhere on the board
GND: C1.2, C2.2, C5.1, C21.1, C40.2 (C), C85.2 (C), C86.2 (C), C87.2 (C), C88.2 (C), C89.2 (C), C90.2 (C), C91.2 (C), C92.2 (C), C94.2 (C), C96.2 (C), C98.2 (C), C99.2 (C), C100.2, C101.2 (C), C102.2, J5.6 (VSS), JP1.3, JP3.2, SW3.1, SW3.4, U8.3 (GND), U8.13 (GND), U9.16 (VSS), U9.31 (VSSA), U9.38 (VSS), U9.51 (VSS), U9.61 (VSS), U9.83 (VSS), U9.94 (VSS), U9.107 (VSS), U9.120 (VSS), U9.130 (VSS), U9.138 (BOOT0/VPP), X2.GND@1 (1), X2.GND@2 (2), Z3.1 (GND); also elsewhere on the board
MCU_RX_UART3: U8.15 (TXD); also elsewhere on the board
MCU_TX_UART3: U8.2 (RXD); also elsewhere on the board
unnamed: C102.1, U9.106 (VCAP_2)
unnamed: C2.1, U8.1 (VCCIO), U8.8 (3V3OUT), U8.9 (!RESET)
unnamed: C100.1, U9.71 (VCAP_1)
SD0_DAT1: J5.8 (DATA1)
SD0_DAT2: J5.1 (DATA2)
SD0_DAT3: J5.2 (CD/DATA3)
SD2_CLK: J5.5 (CLK); also elsewhere on the board
SD2_CMD: J5.3 (CMD); also elsewhere on the board
SD2_DAT0: J5.7 (DATA0); also elsewhere on the board
SWCLK: JP1.2; also elsewhere on the board
SWDIO: JP1.4; also elsewhere on the board
SWO: JP1.6; also elsewhere on the board
USB_DM: U8.7 (USBDM); also elsewhere on the board
USB_DP: U8.6 (USBDP); also elsewhere on the board
X2: C5.2, U9.24 (PH1-OSC_OUT/EVENTOUT), X2.3

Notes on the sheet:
t.elliott
SWD
USB-2-Serial

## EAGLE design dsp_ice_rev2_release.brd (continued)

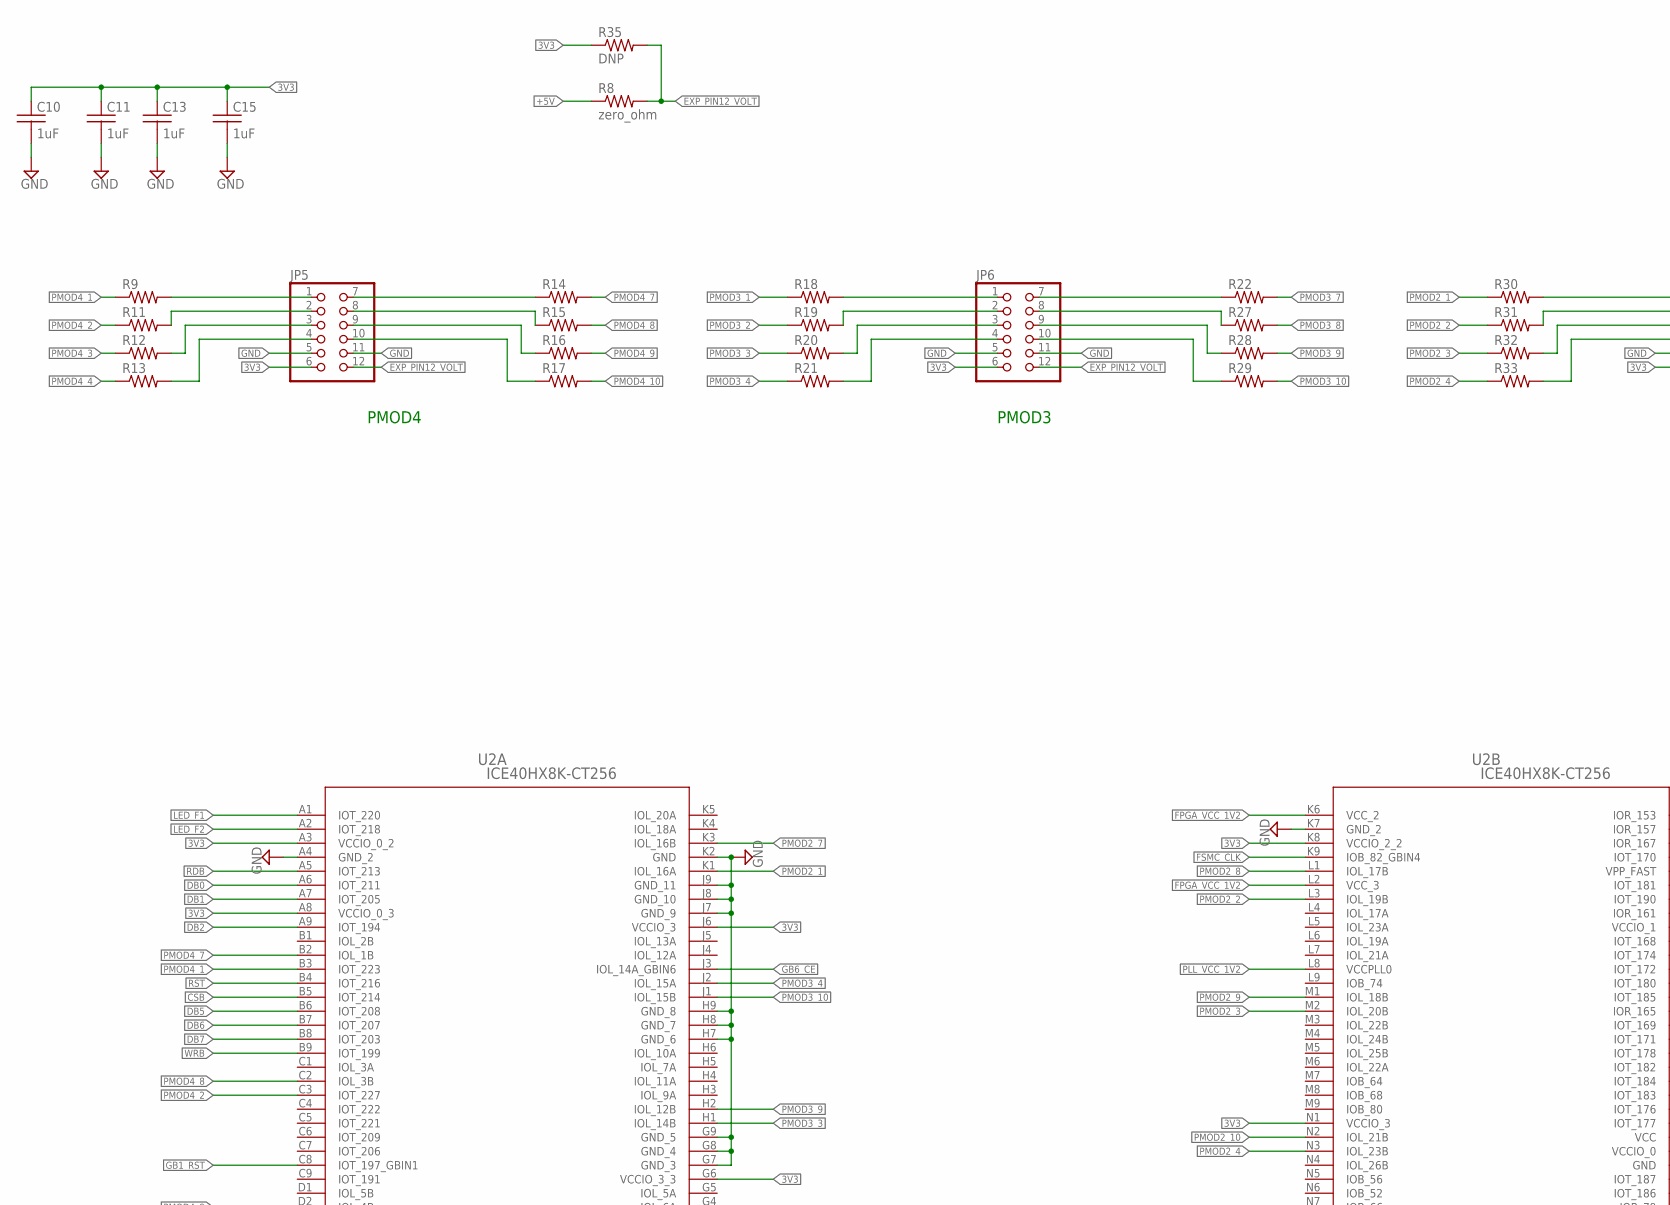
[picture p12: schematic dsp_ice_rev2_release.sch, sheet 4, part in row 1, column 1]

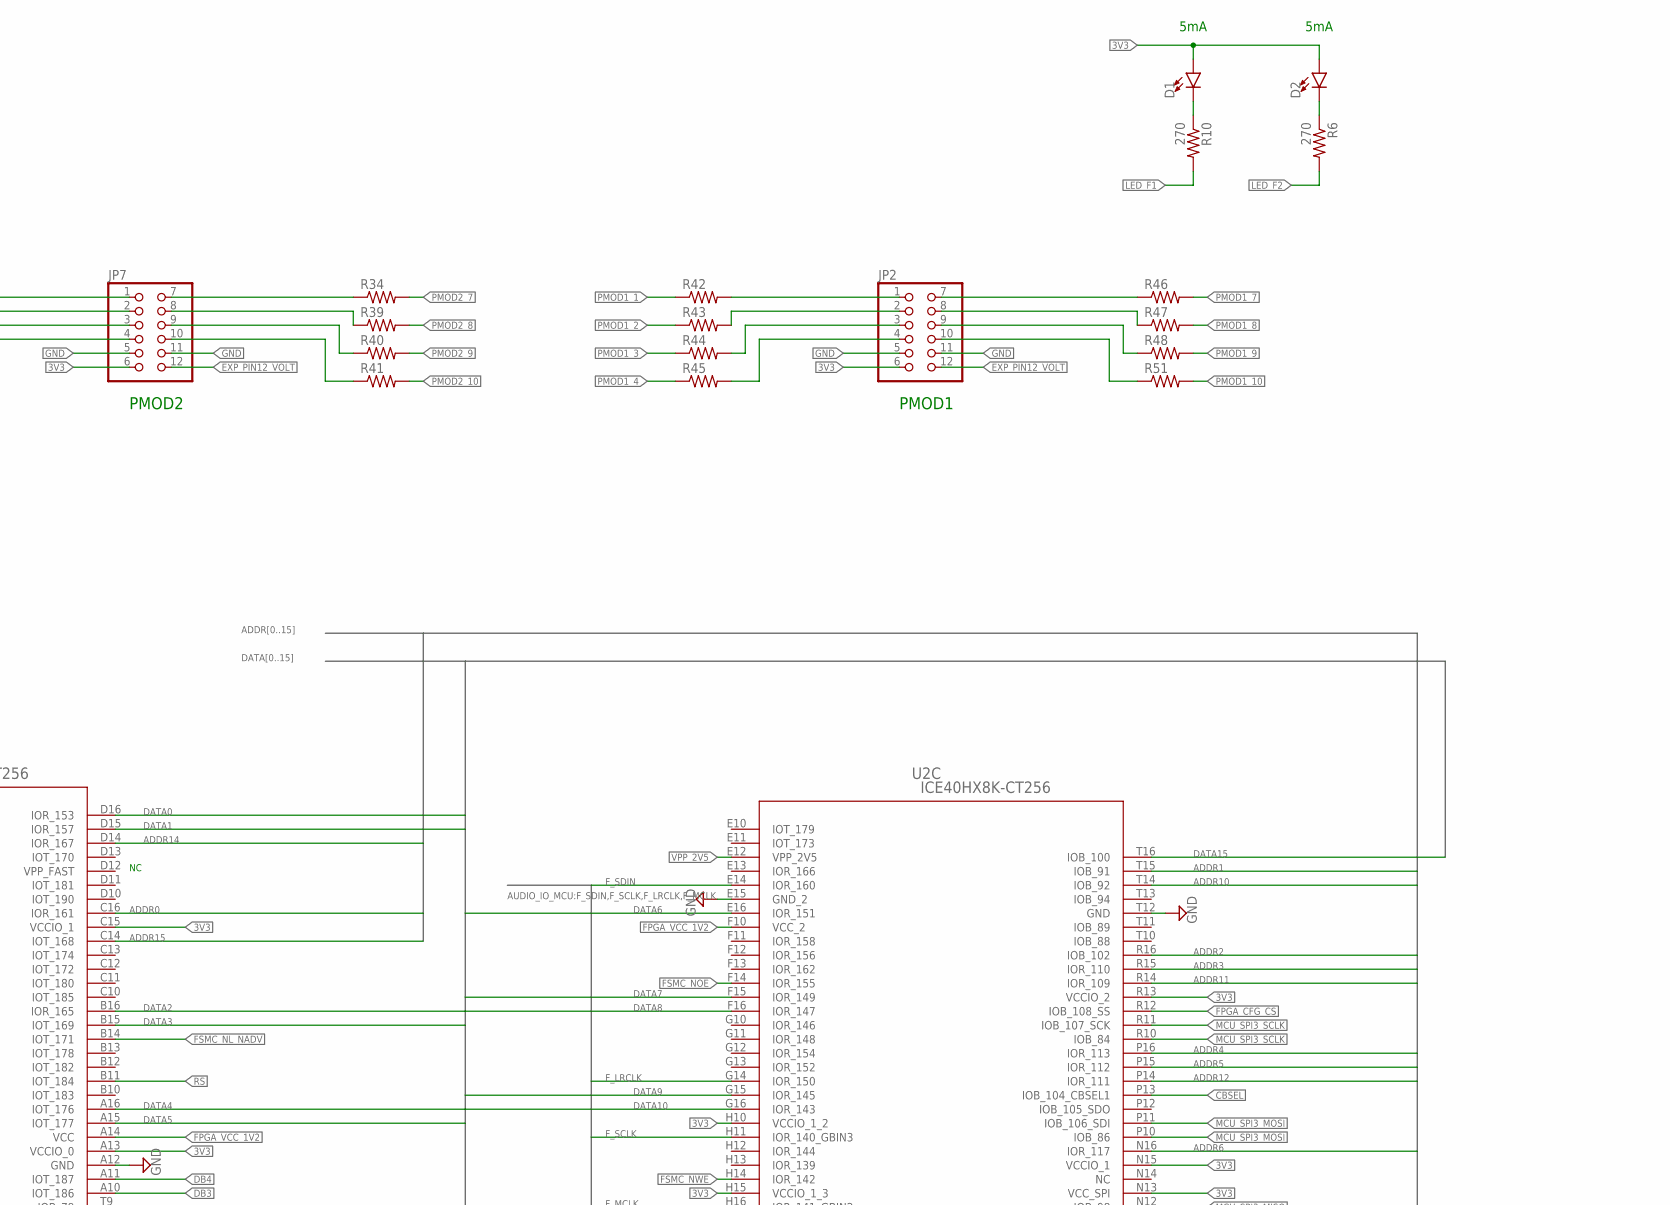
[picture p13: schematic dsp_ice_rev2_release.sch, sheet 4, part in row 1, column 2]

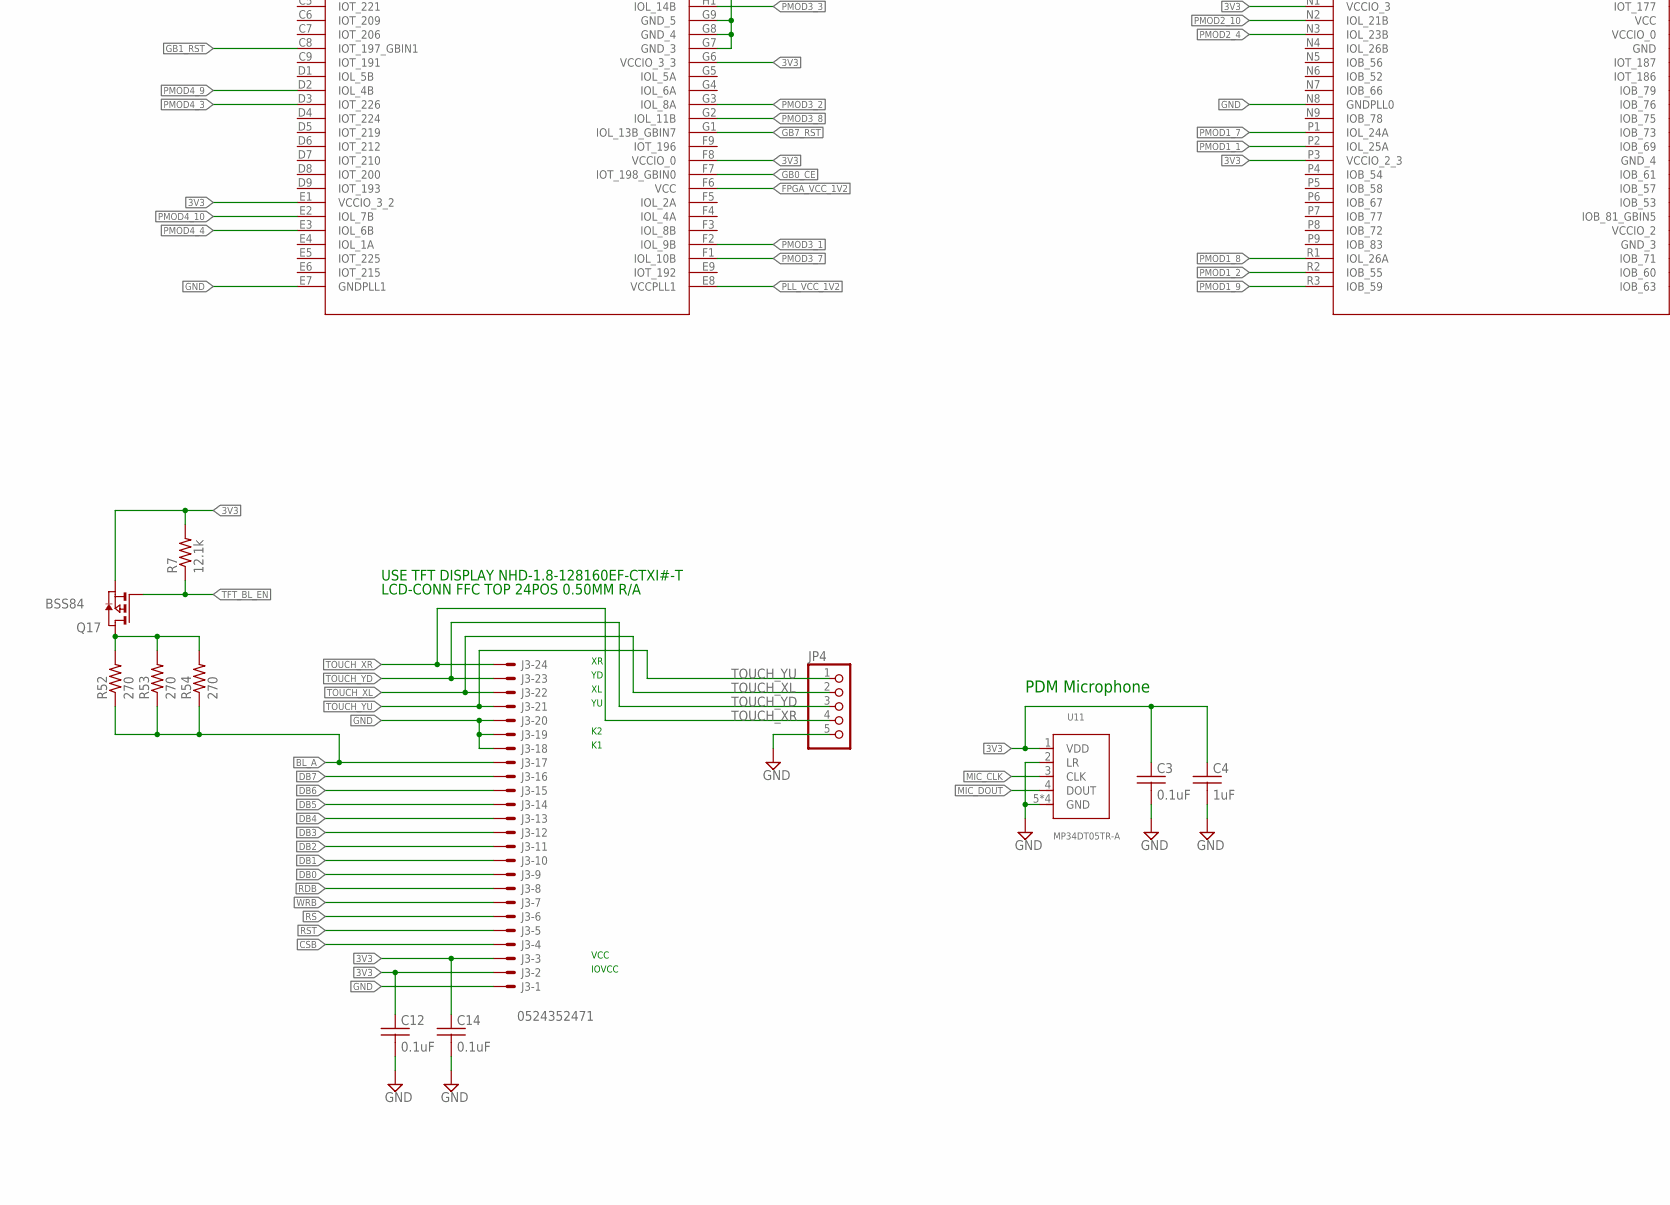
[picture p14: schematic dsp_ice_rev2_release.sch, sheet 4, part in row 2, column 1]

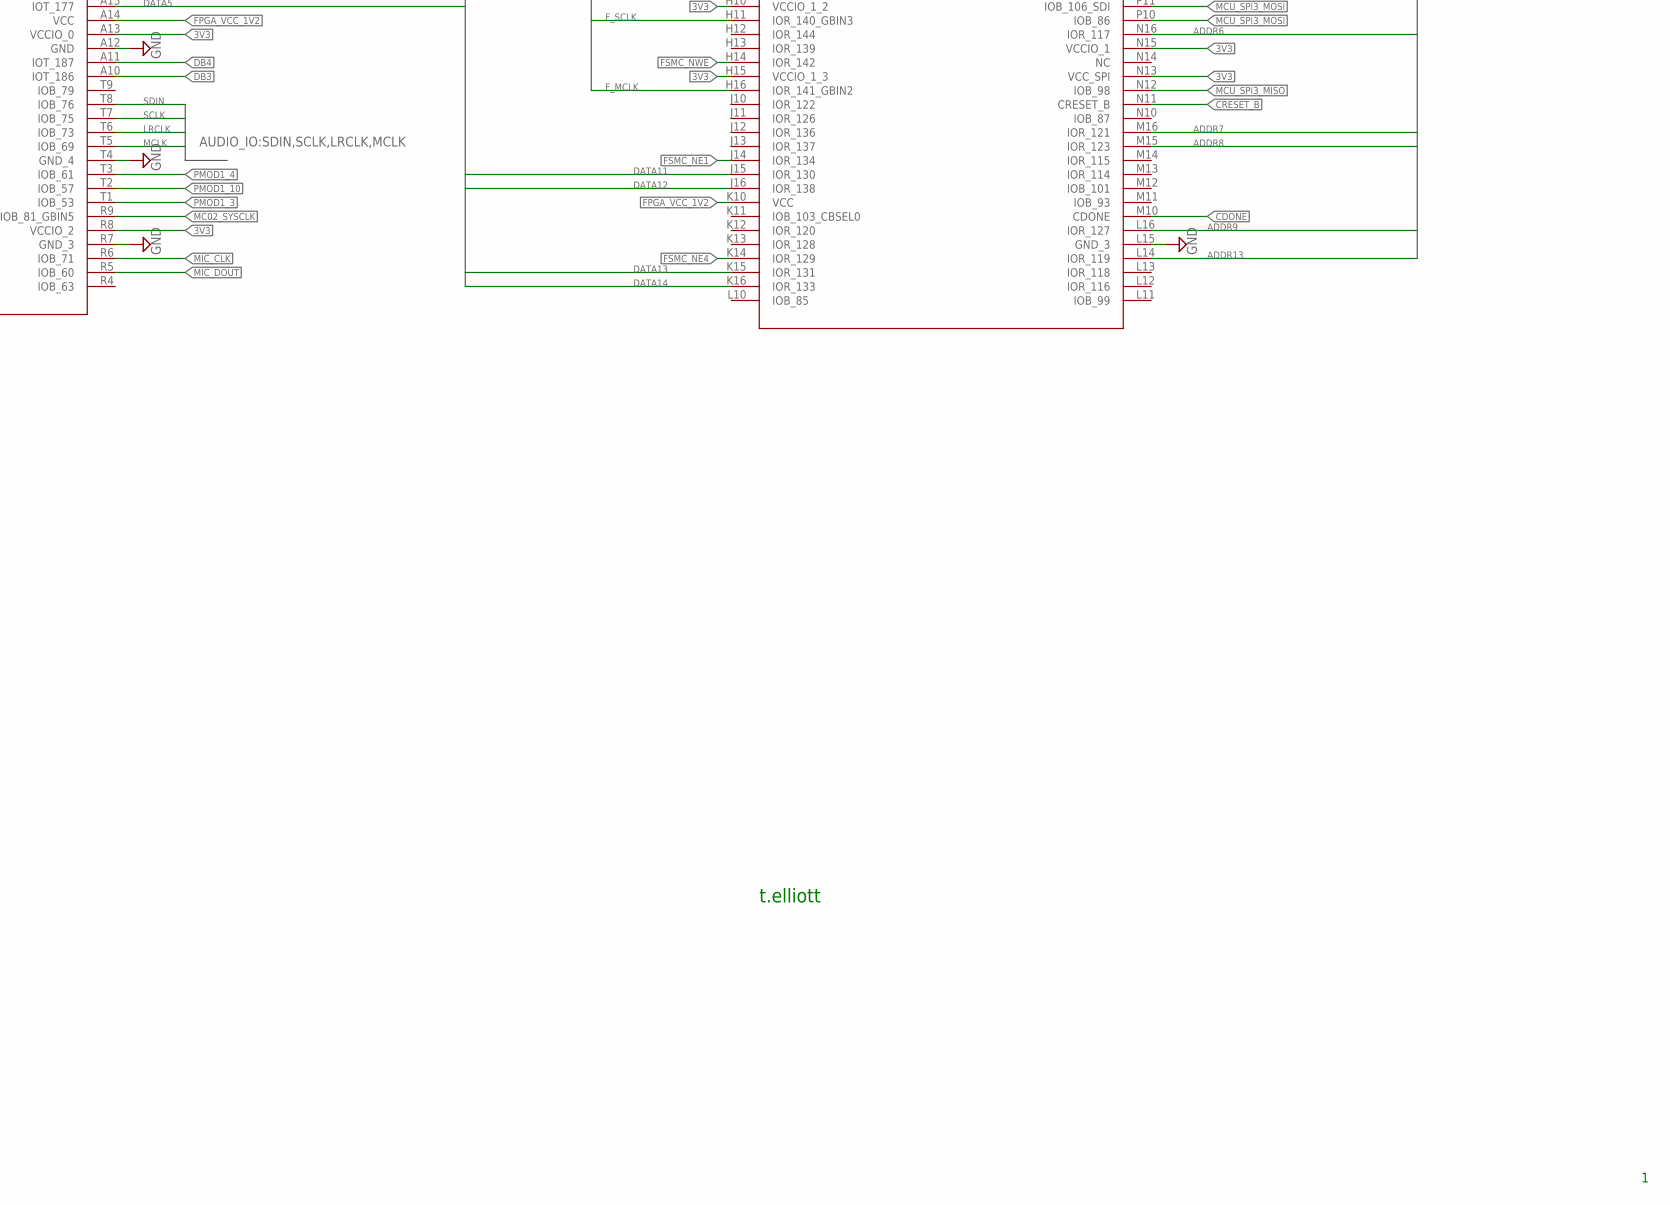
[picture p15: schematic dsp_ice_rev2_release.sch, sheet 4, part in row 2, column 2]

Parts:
C3, C12, C14: 0.1uF; C0603
C4, C10, C11, C13, C15: 1uF; C0603
D1, D2: LED1206; LED-1206
J3: 0524352471; 52745-2490
JP2, JP5, JP6, JP7: PINHD-2X6; 2X06
JP4: PINHD-1X5; 1X05
Q17: BSS84; SOT23_BSS84_PACKAGE
R6, R10, R52, R53, R54: 270; R0603
R7: 12.1k; R0603
R8: zero_ohm; R1206W
R9, R11, R12, R13, R14, R15, R16, R17, R18, R19, R20, R21, R22, R27, R28, R29, R30, R31, R32, R33, R34, R39, R40, R41, R42, R43, R44, R45, R46, R47, R48, R51: 10; R0603
R35: DNP; R1206W
U2: ICE40HX8K-CT256; CABGA256
U11: MP34DT05TR-A; HCLGA5P-3X4X1MM

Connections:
3V3: C3.1, C4.1, C10.1, C11.1, C12.1, C13.1, C14.1, C15.1, D1.A, D2.A, J3.2, J3.3, JP2.6 (11), JP5.6 (11), JP6.6 (11), JP7.6 (11), Q17.2 (S), R7.2, R35.1, U2.A3 (VCCIO_0_2), U2.A8 (VCCIO_0_3), U2.A13 (VCCIO_0), U2.C15 (VCCIO_1), U2.E1 (VCCIO_3_2), U2.F8 (VCCIO_0), U2.G6 (VCCIO_3_3), U2.H10 (VCCIO_1_2), U2.H15 (VCCIO_1_3), U2.J6 (VCCIO_3), U2.K8 (VCCIO_2_2), U2.N1 (VCCIO_3), U2.N13 (VCC_SPI), U2.N15 (VCCIO_1), U2.P3 (VCCIO_2_3), U2.R8 (VCCIO_2), U2.R13 (VCCIO_2), U11.1 (VDD); also elsewhere on the board
+5V: R8.1; also elsewhere on the board
ADDR0: U2.C16 (IOR_161); also elsewhere on the board
ADDR1: U2.T15 (IOB_91); also elsewhere on the board
ADDR2: U2.R16 (IOB_102); also elsewhere on the board
ADDR3: U2.R15 (IOR_110); also elsewhere on the board
ADDR4: U2.P16 (IOR_113); also elsewhere on the board
ADDR5: U2.P15 (IOR_112); also elsewhere on the board
ADDR6: U2.N16 (IOR_117); also elsewhere on the board
ADDR7: U2.M16 (IOR_121); also elsewhere on the board
ADDR8: U2.M15 (IOR_123); also elsewhere on the board
ADDR9: U2.L16 (IOR_127); also elsewhere on the board
ADDR10: U2.T14 (IOB_92); also elsewhere on the board
ADDR11: U2.R14 (IOR_109); also elsewhere on the board
ADDR12: U2.P14 (IOR_111); also elsewhere on the board
ADDR13: U2.L14 (IOR_119); also elsewhere on the board
ADDR14: U2.D14 (IOR_167); also elsewhere on the board
ADDR15: U2.C14 (IOT_168); also elsewhere on the board
BL_A: J3.17, R52.1, R53.1, R54.1
CBSEL: U2.P13 (IOB_104_CBSEL1); also elsewhere on the board
CDONE: U2.M10 (CDONE); also elsewhere on the board
CRESET_B: U2.N11 (CRESET_B); also elsewhere on the board
CSB: J3.4, U2.B5 (IOT_214)
DATA0: U2.D16 (IOR_153); also elsewhere on the board
DATA1: U2.D15 (IOR_157); also elsewhere on the board
DATA2: U2.B16 (IOR_165); also elsewhere on the board
DATA3: U2.B15 (IOT_169); also elsewhere on the board
DATA4: U2.A16 (IOT_176); also elsewhere on the board
DATA5: U2.A15 (IOT_177); also elsewhere on the board
DATA6: U2.E16 (IOR_151); also elsewhere on the board
DATA7: U2.F15 (IOR_149); also elsewhere on the board
DATA8: U2.F16 (IOR_147); also elsewhere on the board
DATA9: U2.G15 (IOR_145); also elsewhere on the board
DATA10: U2.G16 (IOR_143); also elsewhere on the board
DATA11: U2.J15 (IOR_130); also elsewhere on the board
DATA12: U2.J16 (IOR_138); also elsewhere on the board
DATA13: U2.K15 (IOR_131); also elsewhere on the board
DATA14: U2.K16 (IOR_133); also elsewhere on the board
DATA15: U2.T16 (IOB_100); also elsewhere on the board
DB0: J3.9, U2.A6 (IOT_211)
DB1: J3.10, U2.A7 (IOT_205)
DB2: J3.11, U2.A9 (IOT_194)
DB3: J3.12, U2.A10 (IOT_186)
DB4: J3.13, U2.A11 (IOT_187)
DB5: J3.14, U2.B6 (IOT_208)
DB6: J3.15, U2.B7 (IOT_207)
DB7: J3.16, U2.B8 (IOT_203)
EXP_PIN12_VOLT: JP2.12, JP5.12, JP6.12, JP7.12, R8.2, R35.2
FPGA_CFG_CS: U2.R12 (IOB_108_SS); also elsewhere on the board
FPGA_VCC_1V2: U2.A14 (VCC), U2.F6 (VCC), U2.F10 (VCC_2), U2.K6 (VCC_2), U2.K10 (VCC), U2.L2 (VCC_3); also elsewhere on the board
FSMC_CLK: U2.K9 (IOB_82_GBIN4); also elsewhere on the board
FSMC_NE1: U2.J14 (IOR_134); also elsewhere on the board
FSMC_NE4: U2.K14 (IOR_129); also elsewhere on the board
FSMC_NL_NADV: U2.B14 (IOT_171); also elsewhere on the board
FSMC_NOE: U2.F14 (IOR_155); also elsewhere on the board
FSMC_NWE: U2.H14 (IOR_142); also elsewhere on the board
F_LRCLK: U2.G14 (IOR_150); also elsewhere on the board
F_MCLK: U2.H16 (IOR_141_GBIN2); also elsewhere on the board
F_SCLK: U2.H11 (IOR_140_GBIN3); also elsewhere on the board
F_SDIN: U2.E14 (IOR_160); also elsewhere on the board
GB0_CE: U2.F7 (IOT_198_GBIN0)
GB1_RST: U2.C8 (IOT_197_GBIN1)
GB6_CE: U2.J3 (IOL_14A_GBIN6)
GB7_RST: U2.G1 (IOL_13B_GBIN7)
GND: C3.2, C4.2, C10.2, C11.2, C12.2, C13.2, C14.2, C15.2, J3.1, J3.18, J3.19, J3.20, JP2.5 (9), JP2.11 (10), JP4.5, JP5.5 (9), JP5.11 (10), JP6.5 (9), JP6.11 (10), JP7.5 (9), JP7.11 (10), U2.A4 (GND_2), U2.A12 (GND), U2.E7 (GNDPLL1), U2.E15 (GND_2), U2.G7 (GND_3), U2.G8 (GND_4), U2.G9 (GND_5), U2.H7 (GND_6), U2.H8 (GND_7), U2.H9 (GND_8), U2.J7 (GND_9), U2.J8 (GND_10), U2.J9 (GND_11), U2.K2 (GND), U2.K7 (GND_2), U2.L15 (GND_3), U2.N8 (GNDPLL0), U2.R7 (GND_3), U2.T4 (GND_4), U2.T12 (GND), U11.2 (LR), U11.5 (GND), U11.6 (GND), U11.7 (GND), U11.8 (GND); also elsewhere on the board
LED_F1: R10.2, U2.A1 (IOT_220)
LED_F2: R6.2, U2.A2 (IOT_218)
LRCLK: U2.T6 (IOB_73); also elsewhere on the board
MC02_SYSCLK: U2.R9 (IOB_81_GBIN5); also elsewhere on the board
MCLK: U2.T5 (IOB_69); also elsewhere on the board
MCU_SPI3_MISO: U2.N12 (IOB_98); also elsewhere on the board
MCU_SPI3_MOSI: U2.P10 (IOB_86), U2.P11 (IOB_106_SDI); also elsewhere on the board
MCU_SPI3_SCLK: U2.R10 (IOB_84), U2.R11 (IOB_107_SCK); also elsewhere on the board
MIC_CLK: U2.R6 (IOB_71), U11.3 (CLK)
MIC_DOUT: U2.R5 (IOB_60), U11.4 (DOUT)
unnamed: Q17.3 (D), R52.2, R53.2, R54.2
unnamed: D1.C, R10.1
unnamed: D2.C, R6.1
unnamed: JP5.1, R9.2
unnamed: JP5.2 (3), R11.2
unnamed: JP5.3 (5), R12.2
unnamed: JP5.4 (7), R13.2
unnamed: JP5.10 (8), R17.1
unnamed: JP5.9 (6), R16.1
unnamed: JP5.8 (4), R15.1
unnamed: JP5.7 (2), R14.1
unnamed: JP6.1, R18.2
unnamed: JP6.2 (3), R19.2
unnamed: JP6.3 (5), R20.2
unnamed: JP6.4 (7), R21.2
unnamed: JP6.7 (2), R22.1
unnamed: JP6.8 (4), R27.1
unnamed: JP6.9 (6), R28.1
unnamed: JP6.10 (8), R29.1
unnamed: JP7.1, R30.2
unnamed: JP7.2 (3), R31.2
unnamed: JP7.3 (5), R32.2
unnamed: JP7.4 (7), R33.2
unnamed: JP7.7 (2), R34.1
unnamed: JP7.8 (4), R39.1
unnamed: JP7.9 (6), R40.1
unnamed: JP7.10 (8), R41.1
unnamed: JP2.1, R42.2
unnamed: JP2.2 (3), R43.2
unnamed: JP2.3 (5), R44.2
unnamed: JP2.4 (7), R45.2
unnamed: JP2.7 (2), R46.1
unnamed: JP2.8 (4), R47.1
unnamed: JP2.9 (6), R48.1
unnamed: JP2.10 (8), R51.1
PLL_VCC_1V2: U2.E8 (VCCPLL1), U2.L8 (VCCPLL0); also elsewhere on the board
PMOD1_1: R42.1, U2.P2 (IOL_25A)
PMOD1_2: R43.1, U2.R2 (IOB_55)
PMOD1_3: R44.1, U2.T1 (IOB_53)
PMOD1_4: R45.1, U2.T3 (IOB_61)
PMOD1_7: R46.2, U2.P1 (IOL_24A)
PMOD1_8: R47.2, U2.R1 (IOL_26A)
PMOD1_9: R48.2, U2.R3 (IOB_59)
PMOD1_10: R51.2, U2.T2 (IOB_57)
PMOD2_1: R30.1, U2.K1 (IOL_16A)
PMOD2_2: R31.1, U2.L3 (IOL_19B)
PMOD2_3: R32.1, U2.M2 (IOL_20B)
PMOD2_4: R33.1, U2.N3 (IOL_23B)
PMOD2_7: R34.2, U2.K3 (IOL_16B)
PMOD2_8: R39.2, U2.L1 (IOL_17B)
PMOD2_9: R40.2, U2.M1 (IOL_18B)
PMOD2_10: R41.2, U2.N2 (IOL_21B)
PMOD3_1: R18.1, U2.F2 (IOL_9B)
PMOD3_2: R19.1, U2.G3 (IOL_8A)
PMOD3_3: R20.1, U2.H1 (IOL_14B)
PMOD3_4: R21.1, U2.J2 (IOL_15A)
PMOD3_7: R22.2, U2.F1 (IOL_10B)
PMOD3_8: R27.2, U2.G2 (IOL_11B)
PMOD3_9: R28.2, U2.H2 (IOL_12B)
PMOD3_10: R29.2, U2.J1 (IOL_15B)
PMOD4_1: R9.1, U2.B3 (IOT_223)
PMOD4_2: R11.1, U2.C3 (IOT_227)
PMOD4_3: R12.1, U2.D3 (IOT_226)
PMOD4_4: R13.1, U2.E3 (IOL_6B)
PMOD4_7: R14.2, U2.B2 (IOL_1B)
PMOD4_8: R15.2, U2.C2 (IOL_3B)
PMOD4_9: R16.2, U2.D2 (IOL_4B)
PMOD4_10: R17.2, U2.E2 (IOL_7B)
RDB: J3.8, U2.A5 (IOT_213)
RS: J3.6, U2.B11 (IOT_184)
RST: J3.5, U2.B4 (IOT_216)
SCLK: U2.T7 (IOB_75); also elsewhere on the board
SDIN: U2.T8 (IOB_76); also elsewhere on the board
TFT_BL_EN: Q17.1 (G), R7.1; also elsewhere on the board
TOUCH_XL: J3.22, JP4.2; also elsewhere on the board
TOUCH_XR: J3.24, JP4.4; also elsewhere on the board
TOUCH_YD: J3.23, JP4.3; also elsewhere on the board
TOUCH_YU: J3.21, JP4.1; also elsewhere on the board
VPP_2V5: U2.E12 (VPP_2V5); also elsewhere on the board
VPP_FAST: U2.D12 (VPP_FAST)
WRB: J3.7, U2.B9 (IOT_199)

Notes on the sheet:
5mA
PMOD4
PMOD3
PMOD2
PMOD1
t.elliott
LCD-CONN FFC TOP 24POS 0.50MM R/A
USE TFT DISPLAY NHD-1.8-128160EF-CTXI#-T
PDM Microphone
VCC
IOVCC

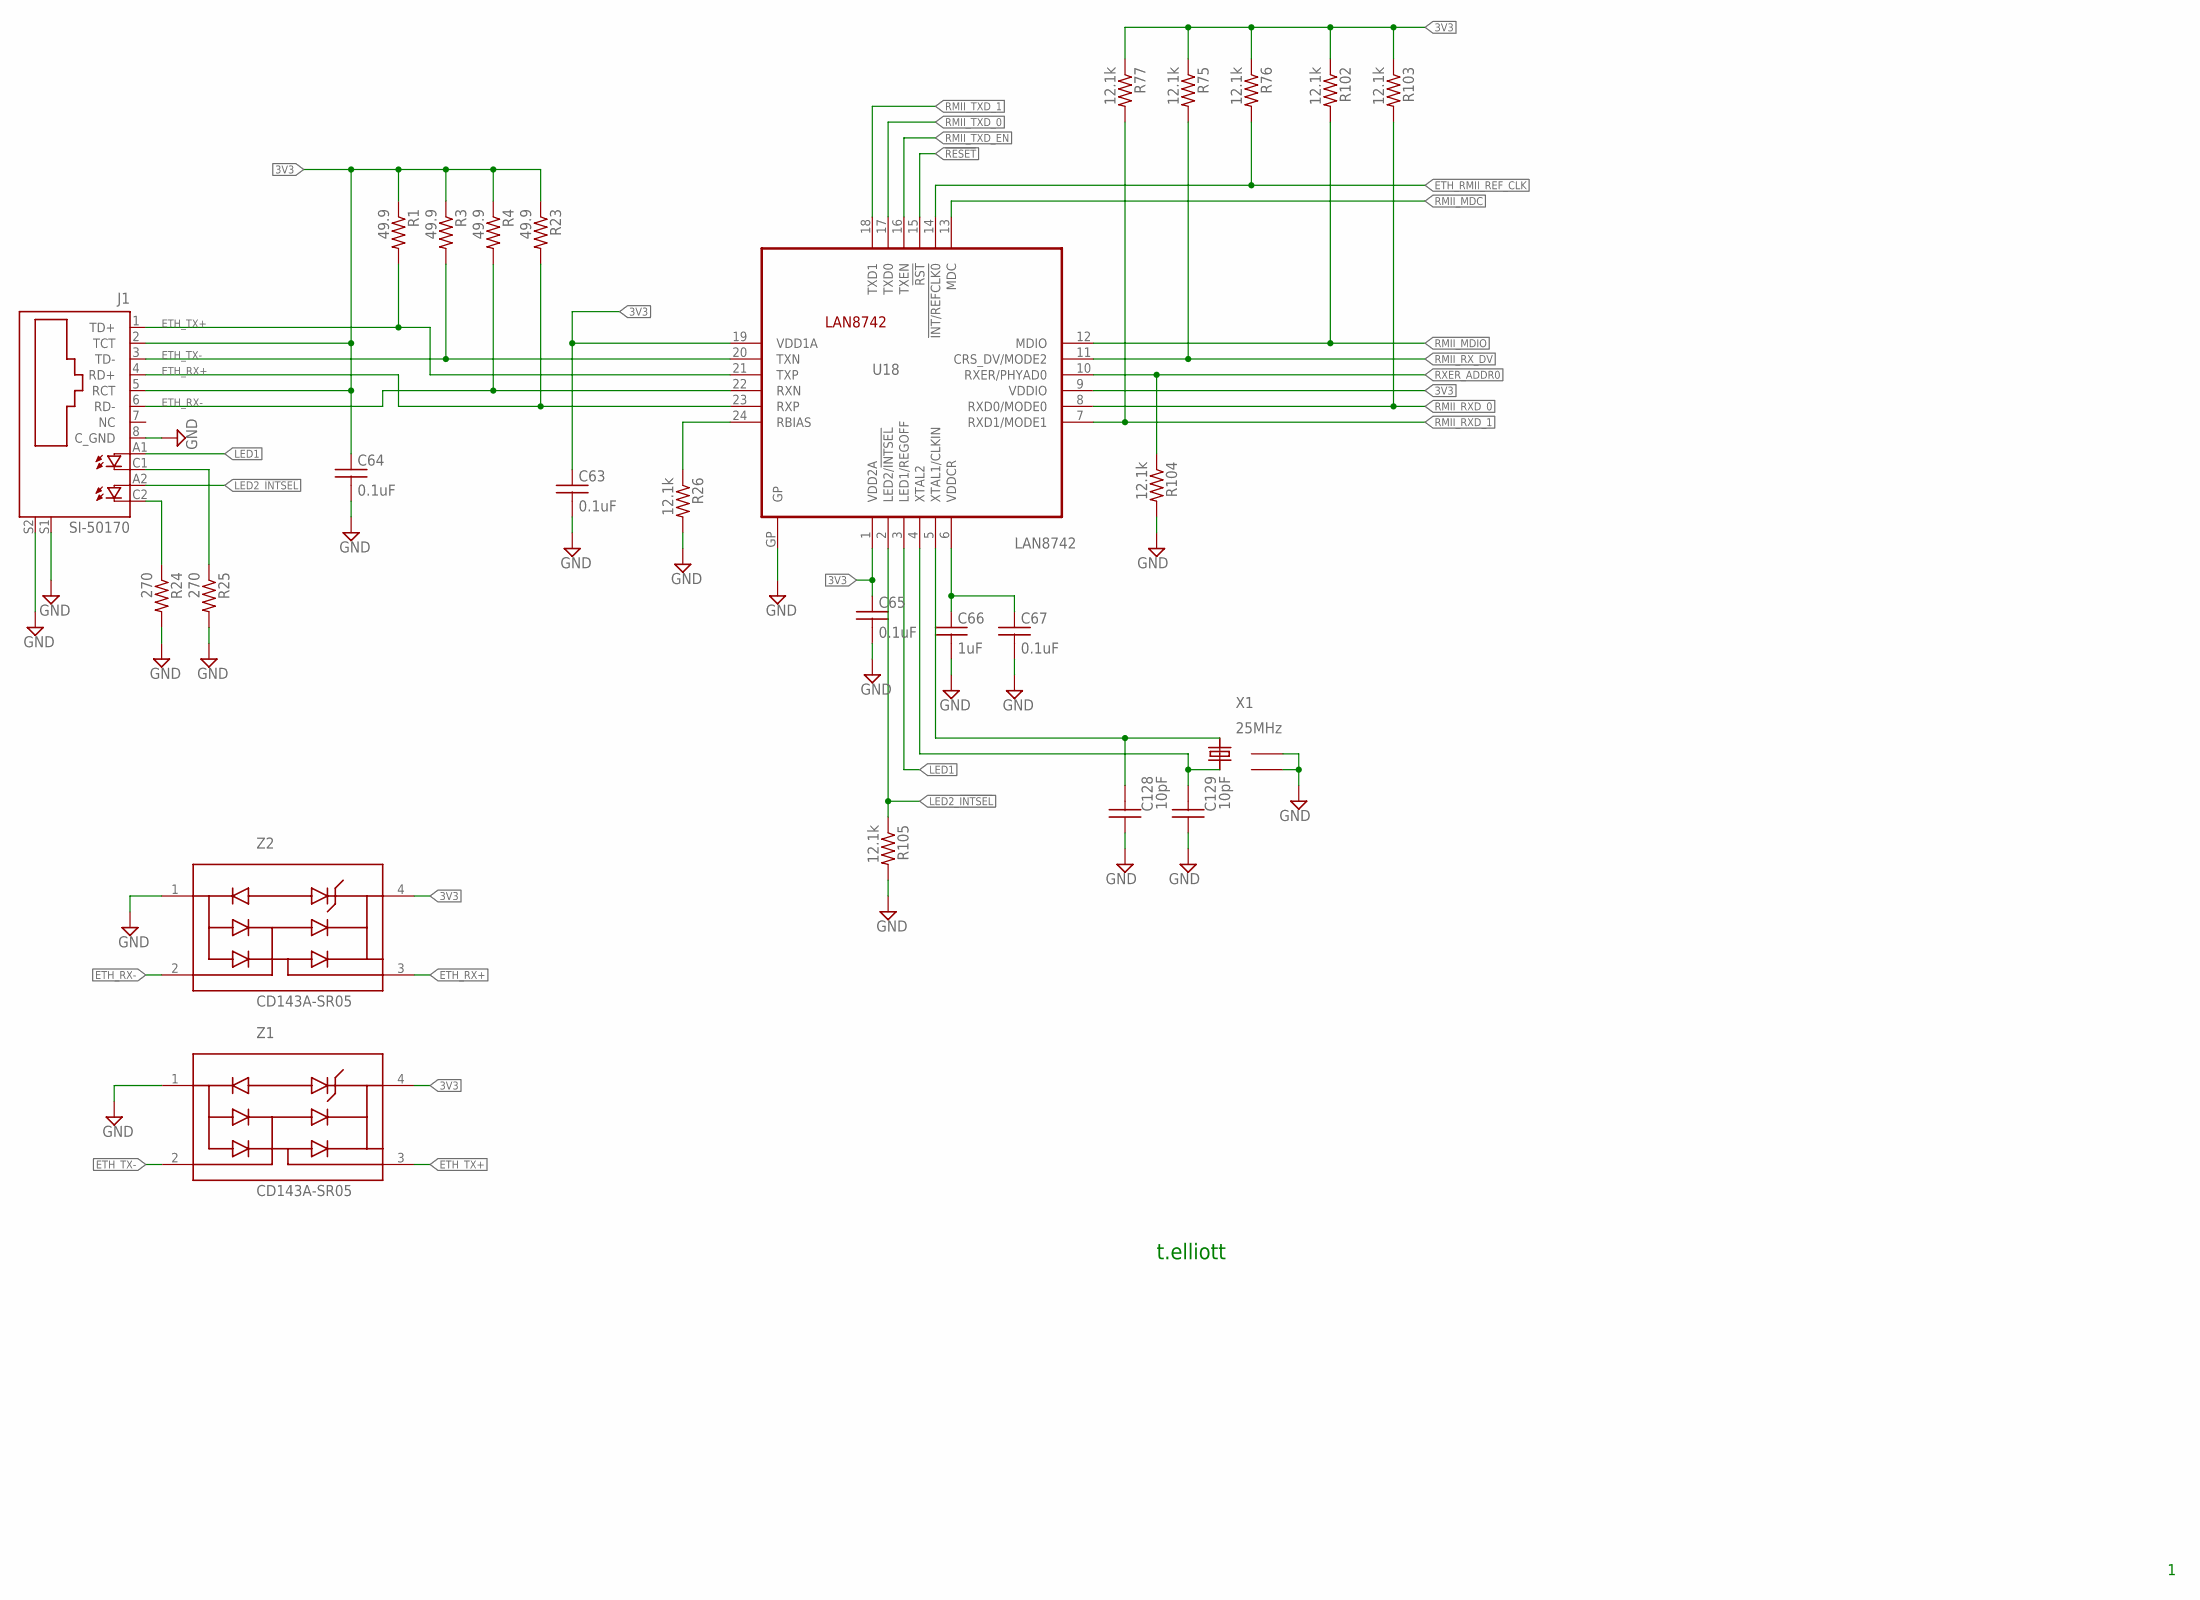
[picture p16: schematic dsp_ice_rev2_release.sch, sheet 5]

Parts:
C63, C64, C65, C67: 0.1uF; C0603
C66: 1uF; C0603
C128, C129: 10pF; C0402
J1: SI-50170
R1, R3, R4, R23: 49.9; R0603
R24, R25: 270; R0603
R26, R75, R76, R77, R102, R103, R104, R105: 12.1k; R0603
U18: LAN8742; QFN-24
X1: 25MHz; ECS-250-20-30B-DU_CRYSTAL
Z1, Z2: CD143A-SR05; SR2.8.TCT_1PRIMARY

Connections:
3V3: C63.1, C64.1, C65.1, J1.2 (TCT), J1.5 (RCT), R1.1, R3.1, R4.1, R23.1, R75.1, R76.1, R77.1, R102.1, R103.1, U18.1 (VDD2A), U18.9 (VDDIO), U18.19 (VDD1A), Z1.4 (REF), Z2.4 (REF); also elsewhere on the board
!RESET: U18.15 (!RST); also elsewhere on the board
ETH_RMII_REF_CLK: R76.2, U18.14 (!INT/REFCLK0); also elsewhere on the board
ETH_RX+: J1.4 (RD+), R23.2, U18.23 (RXP), Z2.3 (I/O)
ETH_RX-: J1.6 (RD-), R4.2, U18.22 (RXN), Z2.2 (I/O)
ETH_TX+: J1.1 (TD+), R1.2, U18.21 (TXP), Z1.3 (I/O)
ETH_TX-: J1.3 (TD-), R3.2, U18.20 (TXN), Z1.2 (I/O)
GND: C63.2, C64.2, C65.2, C66.2, C67.2, C128.1, C129.1, J1.8 (C_GND), J1.S1, J1.S2, R24.2, R25.2, R26.2, R104.2, R105.2, U18.GP, X1.GND@1 (1), X1.GND@2 (2), Z1.1 (GND), Z2.1 (GND); also elsewhere on the board
LED1: J1.A1 (A), U18.3 (LED1/REGOFF)
LED2_!INTSEL: J1.A2 (A1), R105.1, U18.2 (LED2/!INTSEL)
unnamed: R26.1, U18.24 (RBIAS)
unnamed: C66.1, C67.1, U18.6 (VDDCR)
unnamed: J1.C2 (C1), R24.1
unnamed: J1.C1 (C), R25.1
unnamed: C129.2, U18.4 (XTAL2), X1.3
unnamed: C128.2, U18.5 (XTAL1/CLKIN), X1.1
RMII_MDC: U18.13 (MDC); also elsewhere on the board
RMII_MDIO: R102.2, U18.12 (MDIO); also elsewhere on the board
RMII_RXD_0: R103.2, U18.8 (RXD0/MODE0); also elsewhere on the board
RMII_RXD_1: R77.2, U18.7 (RXD1/MODE1); also elsewhere on the board
RMII_RX_DV: R75.2, U18.11 (CRS_DV/MODE2); also elsewhere on the board
RMII_TXD_0: U18.17 (TXD0); also elsewhere on the board
RMII_TXD_1: U18.18 (TXD1); also elsewhere on the board
RMII_TXD_EN: U18.16 (TXEN); also elsewhere on the board
RXER_ADDR0: R104.1, U18.10 (RXER/PHYAD0)

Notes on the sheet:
t.elliott

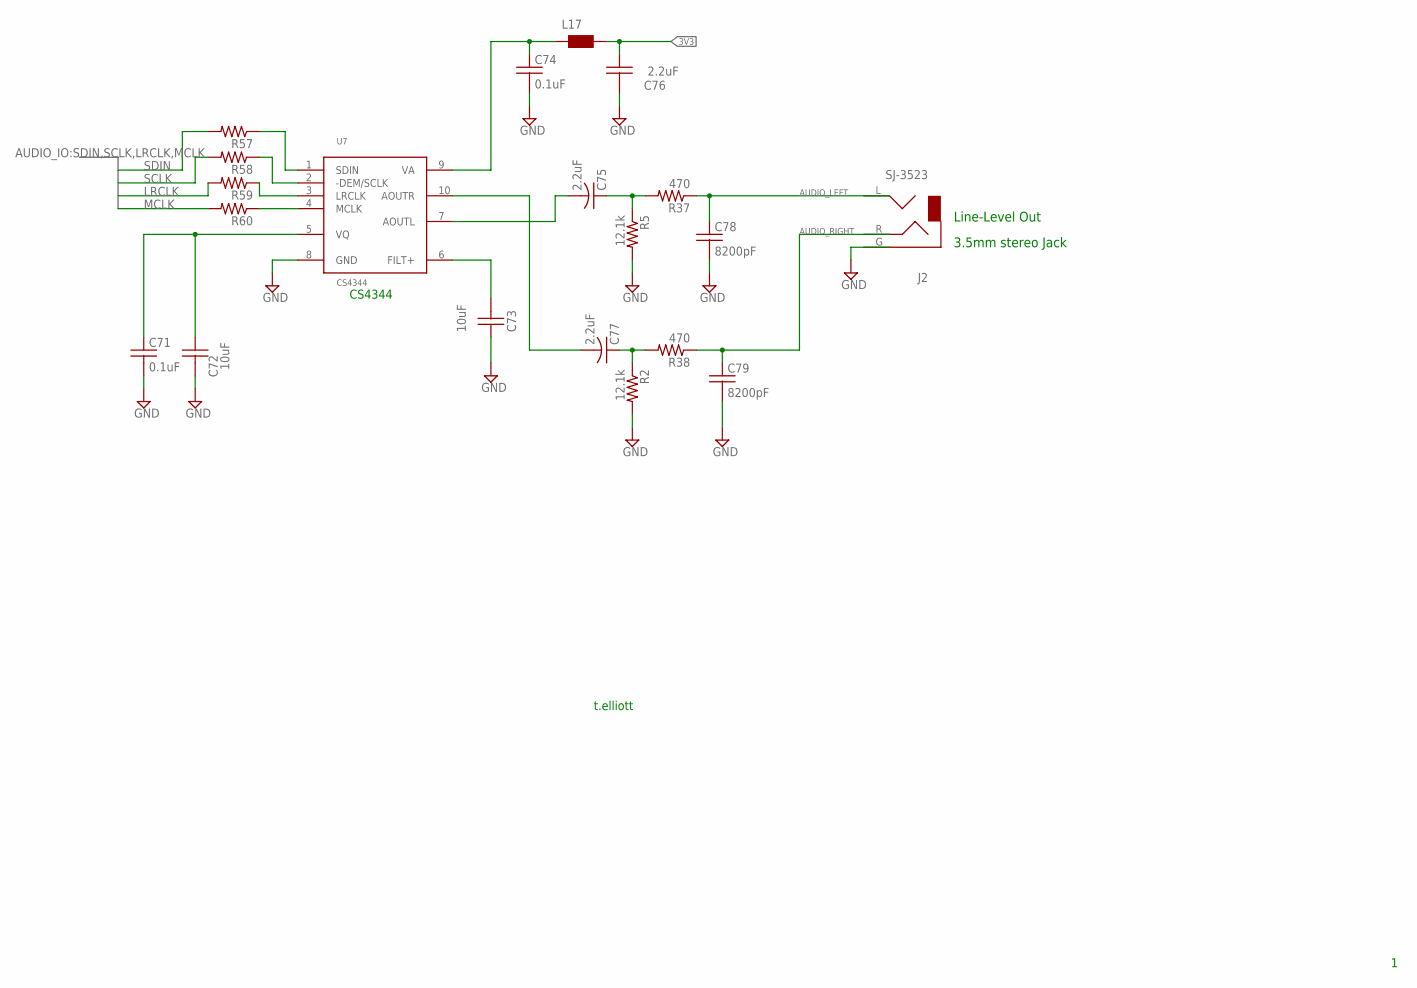
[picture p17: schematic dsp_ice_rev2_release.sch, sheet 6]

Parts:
C71, C74: 0.1uF; C0603
C72, C73: 10uF; C0805
C75, C76, C77: 2.2uF; C0805
C78, C79: 8200pF; C0603
J2: SJ-3523
L17: WE-CBF_0603; 0603
R2, R5: 12.1k; R0603
R37, R38, R57, R58, R59, R60: 470; R0402
U7: CS4344; MSOP10

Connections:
3V3: C76.1, L17.2; also elsewhere on the board
AUDIO_LEFT: C79.1, J2.R, R38.1
AUDIO_RIGHT: C78.1, J2.L, R37.1
GND: C71.2, C72.2, C73.1, C74.2, C76.2, C78.2, C79.2, J2.G, R2.2, R5.2, U7.8 (GND); also elsewhere on the board
LRCLK: R59.2; also elsewhere on the board
MCLK: R60.2; also elsewhere on the board
unnamed: C77.2, U7.10 (AOUTR)
unnamed: R60.1, U7.4 (MCLK)
unnamed: R59.1, U7.3 (LRCLK)
unnamed: R58.1, U7.2 (-DEM/SCLK)
unnamed: R57.1, U7.1 (SDIN)
unnamed: C73.2, U7.6 (FILT+)
unnamed: C71.1, C72.1, U7.5 (VQ)
unnamed: C75.2, U7.7 (AOUTL)
unnamed: C75.1, R5.1, R37.2
unnamed: C77.1, R2.1, R38.2
unnamed: C74.1, L17.1, U7.9 (VA)
SCLK: R58.2; also elsewhere on the board
SDIN: R57.2; also elsewhere on the board

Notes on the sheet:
t.elliott
CS4344
Line-Level Out
3.5mm stereo Jack

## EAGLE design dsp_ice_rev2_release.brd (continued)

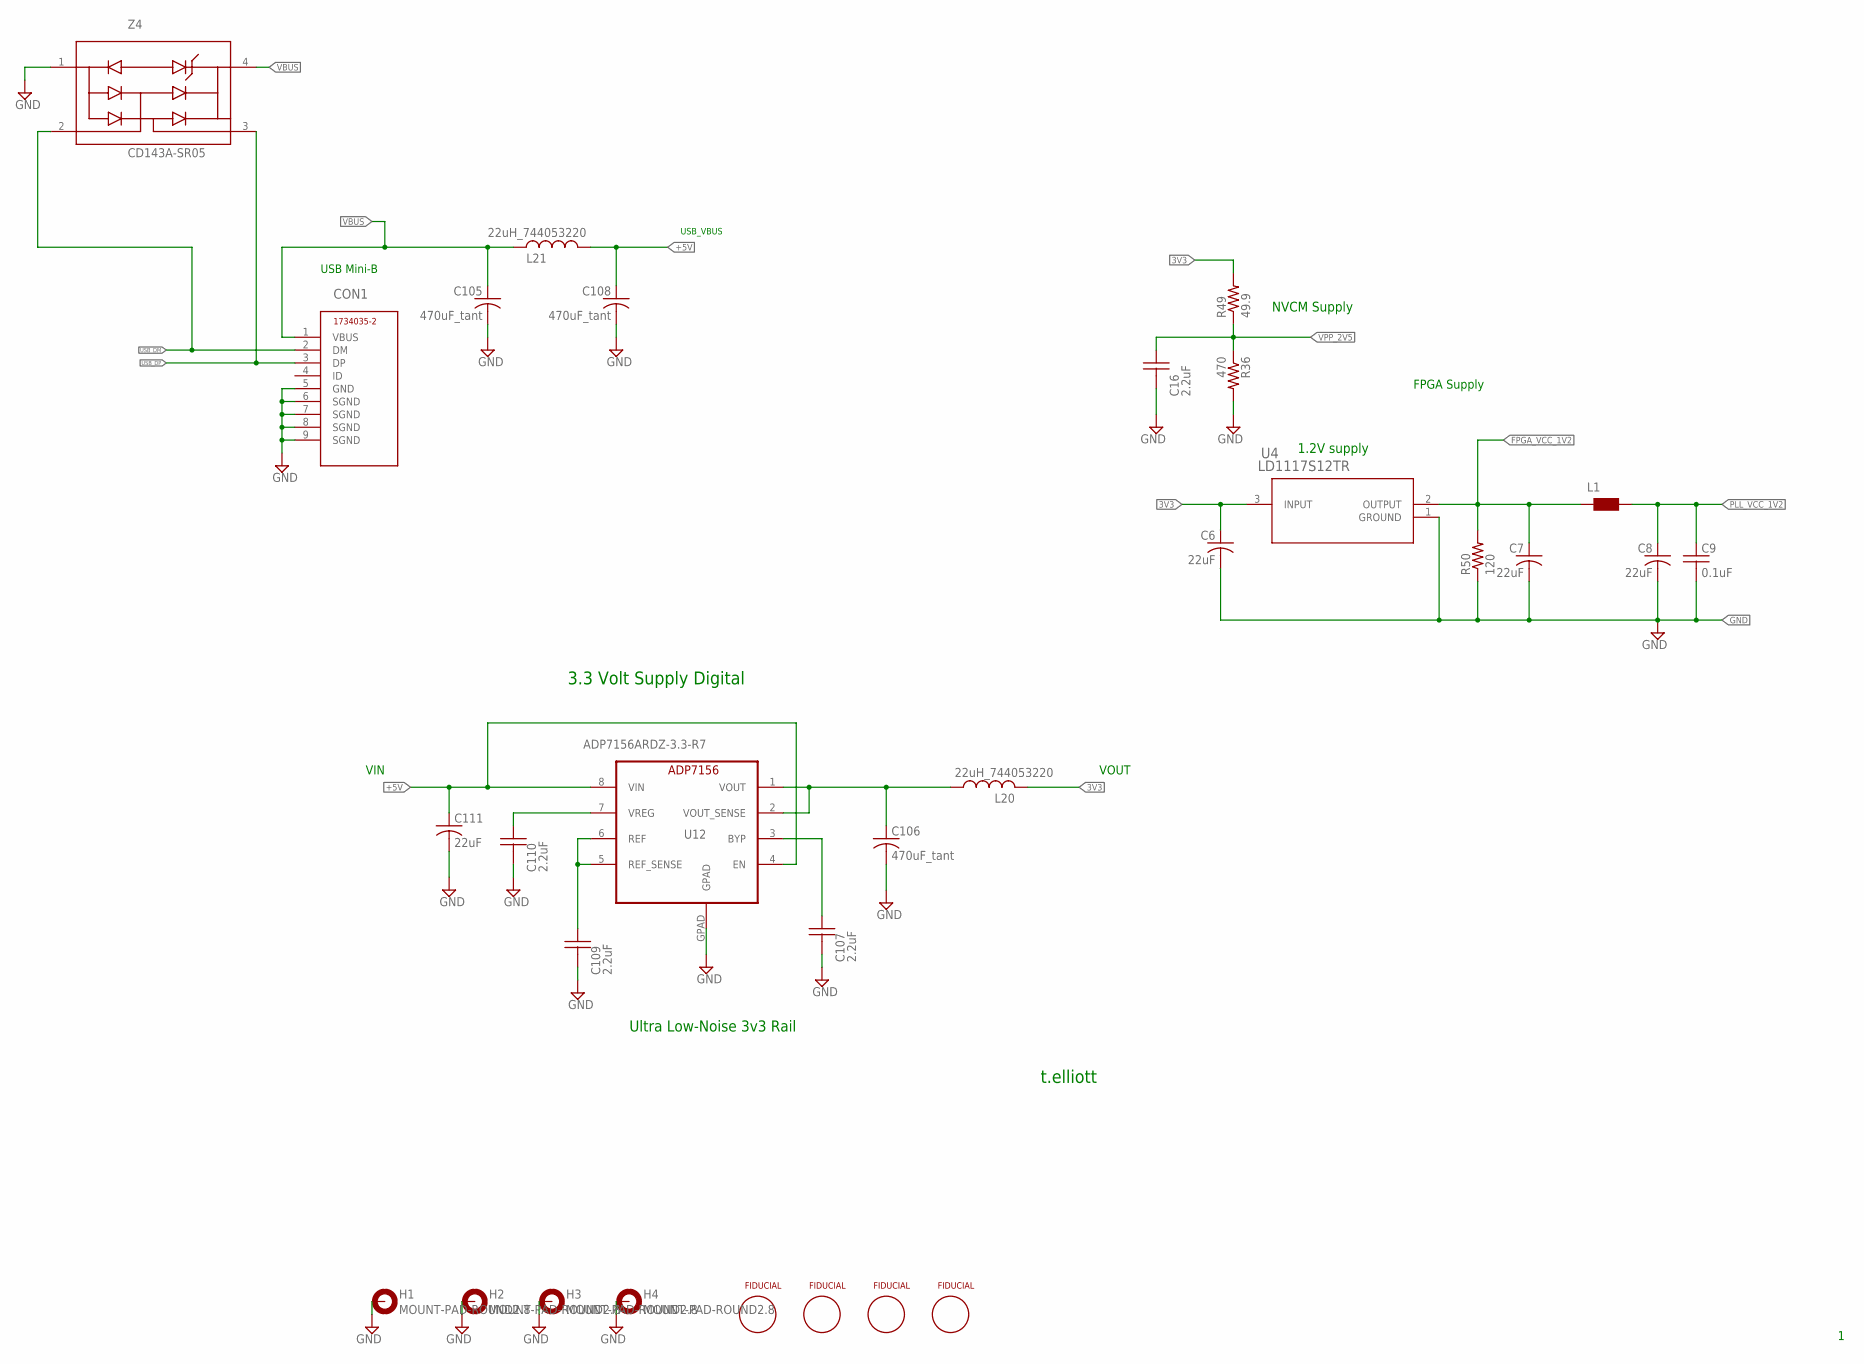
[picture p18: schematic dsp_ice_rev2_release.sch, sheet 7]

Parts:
C6, C7, C8, C111: 22uF; 1210K
C9: 0.1uF; C0603
C16, C107, C109, C110: 2.2uF; C0805
C105, C106, C108: 470uF_tant; 1210K
CON1: 1734035-2
FID1, FID2, FID3, FID4: FIDUCIALSMD; FIDUCIAL
H1, H2, H3, H4: MOUNT-PAD-ROUND2.8; 2,8-PAD
L1: WE-CBF_0603; 0603
L20, L21: 22uH_744053220; POWER-CHOKE_WE-TPC
R36: 470; R0402
R49: 49.9; R0603
R50: 120; R0603
U4: LD1117S12TR; SOT-223
U12: ADP7156ARDZ-3.3-R7; SO8
Z4: CD143A-SR05; SR2.8.TCT_1PRIMARY

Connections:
3V3: C6.A, L20.2, R49.2, U4.3 (INPUT); also elsewhere on the board
+5V: C108.A, C111.A, L21.1, U12.4 (EN), U12.8 (VIN); also elsewhere on the board
FPGA_VCC_1V2: C7.A, L1.1, R50.2, U4.2 (OUTPUT); also elsewhere on the board
GND: C6.C, C7.C, C8.C, C9.2, C16.2, C105.C, C106.C, C107.2, C108.C, C109.2, C110.2, C111.C, CON1.5 (GND), CON1.6 (SGND), CON1.7 (SGND), CON1.8 (SGND), CON1.9 (SGND), H1.B2,8, H2.B2,8, H3.B2,8, H4.B2,8, R36.2, R50.1, U4.1 (GROUND), U12.GPAD, Z4.1 (GND); also elsewhere on the board
unnamed: C106.A, L20.1, U12.1 (VOUT), U12.2 (VOUT_SENSE)
unnamed: C109.1, U12.5 (REF_SENSE), U12.6 (REF)
unnamed: C110.1, U12.7 (VREG)
unnamed: C107.1, U12.3 (BYP)
PLL_VCC_1V2: C8.A, C9.1, L1.2; also elsewhere on the board
USB_DM: CON1.2 (DM), Z4.2 (I/O); also elsewhere on the board
USB_DP: CON1.3 (DP), Z4.3 (I/O); also elsewhere on the board
VBUS: C105.A, CON1.1 (VBUS), L21.2, Z4.4 (REF)
VPP_2V5: C16.1, R36.1, R49.1; also elsewhere on the board

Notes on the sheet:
t.elliott
VIN
VOUT
3.3 Volt Supply Digital
USB Mini-B
USB_VBUS
1.2V supply
NVCM Supply
Ultra Low-Noise 3v3 Rail
FPGA Supply

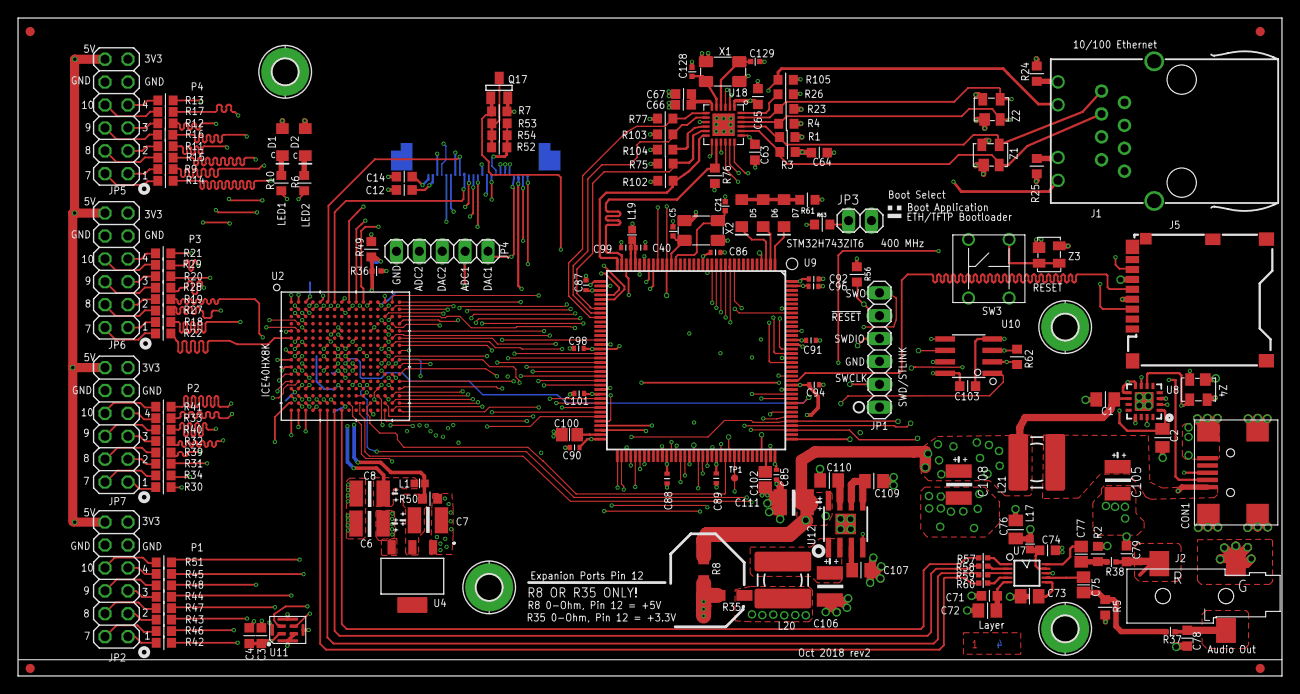
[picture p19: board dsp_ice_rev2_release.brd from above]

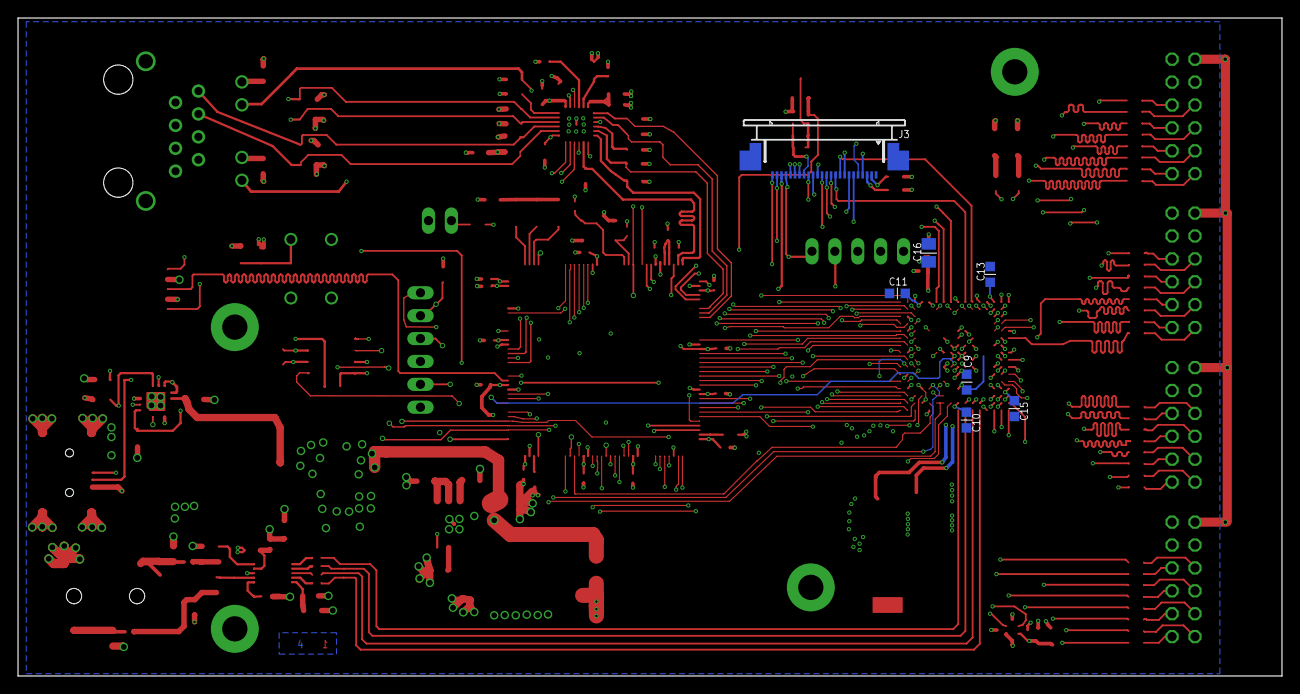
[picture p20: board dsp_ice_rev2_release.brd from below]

Board: 4 copper layers, 140.2 x 73.0 mm, 174 parts (7 on the bottom side), 214 nets.

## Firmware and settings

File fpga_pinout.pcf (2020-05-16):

set_io F_MCLK H16 
set_io LED2 A1 
set_io LED3 A2 
set_io LED4 A5 
set_io clk_in R9 
set_io AUDIO_SDIN T8 
set_io AUDIO_SCLK T7 
set_io AUDIO_LRCLK T6 
set_io AUDIO_MCLK T5 
set_io CBSEL P13
set_io PMOD1_1 P2
set_io PMOD1_2 R2 
set_io PMOD1_3 T1 
set_io PMOD1_4 T3
set_io PMOD1_7 P1
set_io PMOD1_8 R1
set_io PMOD1_9 R3
set_io PMOD1_10 T2
set_io PMOD2_1 K1 
set_io PMOD2_2 L3
set_io PMOD2_3 M2 
set_io PMOD2_4 N3 
set_io PMOD2_7 K3 
set_io PMOD2_8 L1 
set_io PMOD2_9 M1 
set_io PMOD2_10 N2 
set_io PMOD3_1 F2 
set_io PMOD3_2 G3
set_io PMOD3_3 H1 
set_io PMOD3_4 J2 
set_io PMOD3_7 F1 
set_io PMOD3_8 G2 
set_io PMOD3_9 H2 
set_io PMOD3_10 J1 
set_io PMOD4_1 B3 
set_io PMOD4_2 C3 
set_io PMOD4_3 D3 
set_io PMOD4_4 E3 
set_io PMOD4_7 B2 
set_io PMOD4_8 C2 
set_io PMOD4_9 D2 
set_io PMOD4_10 E2 
set_io P_A6 A6 
set_io P_A7 A7 
set_io P_A9 A9 
set_io P_A10 A10 
set_io P_A11 A11 
set_io P_B6 B6 
set_io P_B7 B7 
set_io P_B8 B8 
set_io P_B9 B9 
set_io P_B11 B11 
set_io A0 C16 
set_io A1 T15 
set_io A2 R16 
set_io A3 R15 
set_io A4 P16 
set_io A5 P15 
set_io A6 N16 
set_io A7 M16 
set_io A8 M15 
set_io A9 L16 
set_io A10 T14 
set_io A11 R14  
set_io A12 P14 
set_io A13 L14 
set_io A14 D14 
set_io A15 C14 
set_io D0 D16 
set_io D1 D15 
set_io D2 B16 
set_io D3 B15 
set_io D4 A16 
set_io D5 A15 
set_io D6 E16 
set_io D7 F15 
set_io D8 F16 
set_io D9 G15 
set_io D10 G16 
set_io D11 J15 
set_io D12 J16 
set_io D13 K15 
set_io D14 K16 
set_io D15 T16 
set_io FSMC_NOE F14 
set_io FSMC_NWE H14 
set_io FSMC_NE1 J14 
set_io FSMC_NE4 K14 
set_io FSMC_NL_NADV B14
set_io FPGA_SPI_SCLK R10
set_io FPGA_SPI_MOSI P10
set_io FPGA_SPI_MISO N12
set_io FPGA_SPI_CS T13
set_io FSMC_CLK K9 

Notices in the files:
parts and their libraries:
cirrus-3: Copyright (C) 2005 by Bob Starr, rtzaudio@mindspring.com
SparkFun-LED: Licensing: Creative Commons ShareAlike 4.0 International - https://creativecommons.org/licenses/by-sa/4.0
